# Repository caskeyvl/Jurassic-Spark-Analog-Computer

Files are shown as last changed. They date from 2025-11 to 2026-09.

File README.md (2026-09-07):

# Jurassic Spark Analog Computer
---

## NEW CAPSTONE GROUP - Intro
---

Hello new capstone group! We hope you're excited to continue to develop on top of this project. We hope you find a solid enough foundation built here to continue to expand from, and are excited to see where this project goes in the future.

Look around this repository, and familiarize yourself with it's layout and components. 

## Overview
---

Jurassic Spark's Analog Computer is a device that was designed to be used as the core of a course on control theory that will be offered in the future at CU Boulder. It is an educational device featuring 12 swappable module ports, with four different modules (adder, integrator, subtractor, and gain), each of which are a foundational building block that allow a student to quickly create and test a control design of their own making. Featured is also an on-board 4 channel oscilloscope, allowing students to visualize and compare waveforms produced.

To demonstrate some sort of control, in addition to the analog computer, a tertiary demonstrative device was developed. This device features a ping pong ball in a tube, with a fan that blows up and down the ball. Students will learn to develop and test different methods of controlling the height of the ball, through a feedback loop they develop on the analog computer itself. 

This repository contains all the design files and documentation for the Jurassic Spark Analog Computer, and the demonstrative tertiary system that goes along with it.

## Repository Structure
--- 

A quick description of what exists in each directory:

- **documentation** - design write-ups and reference docs for each subsystem, including [`BOM.md`](documentation/BOM.md) (master bill of materials) and [`Final_Report___Jurassic_Spark.pdf`](documentation/Final_Report___Jurassic_Spark.pdf) (our capstone final report — good background reading, but design details in the rest of this repo take precedence where they disagree)
- **hardware** - all PCB schematics and layouts (Altium `.SchDoc`/`.PcbDoc`), grouped per board: `modules/` (Adder, Gain, Integrator, Subtractor), `power/`, `oscilloscope-adc-hat/`, `mechatronic/`
- **mechanical** - enclosure/housing CAD (Parasolid `.x_t`, plus a `.3mf` for the printable module housing) for the module enclosures and full assemblies
- **mechatronic** - Arduino firmware for the mechatronic (ball-in-tube) system
- **oscilloscope** - all of the source code, along with a couple helper scripts, to the oscilloscope.
- **spice** - SPICE simulation files (`.wxsch`) for the individual analog computer modules (gain, integrator, adder/subtractor)

## Recommended Next Steps (to the new capstone team)
--- 

As you will find out, capstone moves quick, and you will never be able to get everything done that you want to get done. A few things worth picking up early:

- **Mechatronic/oscilloscope PCB bringup:** Unfortunately during our time, we were unable to make some quality of life revisions on the mechatronic PCB, and had to make a proto-board instead of a fully fledged PCB for the oscilloscope. Personally, I would begin here, ordering and verifying design, then reintegrating.
- **Case/power delivery issues:** We have noticed that particularly the gain module, for reasons we could not determine, do not get power delivered to them in certain module bays. It is particularly strange as it's only the gain modules that won't work in certain ports, when the adder/subtractor for example work as expected in those modules. May be worthwhile to consider the power delivery of our system and potentially rework it slightly, or at least figure out what the particular issue is with those certain ports. 
- **Better documentation:** One of the things we sort of ended up pushing off, that we highly reccomend learning from our mistake, is documentation. You will find yourself in capstone spending a lot of time on "documentation" that ends up being used for different capstone requirements, such as PDR, CDR, check ins, etc. We did not do a good enough job keeping this information accessible and separate from our capstone requirements, and thus, things that are more for the user (i.e. a simple user manual) didn't end up getting as much focus at it needed. As such, it might be helpful to spend some time as you try to understand our project and the design decisions that were made, to get some of this put together in a more streamlined manner for the sake of students who in the future will be using these devices.
- **Test bluetooth exporting for Windows:** A known issue that we weren't able to fix in time is exporting screenshots to Windows. In short, Windows requires pairing with the device before the OBEX OPP BlueTooth protocol can proceed and a file can be sent. To fix this, an agent is created that establishes a pairing for the duration of the transfer, and unpairs at the end, however this fix is not tested. The fix can be found in the `windows-bluetooth-pairing-proposal` branch, and once tested can be merged. 
- **`deploy.fish`:** this is a script that was written in order to cross compile the oscilloscope app for the Pi Zero 2W. As it stands, it's not functional as a custom Docker image is used that existed on Logan's local machine. Qt Creator (Qt's own IDE) has support for cross compilation built into the IDE, and is recommended to use their IDE and set up cross compilation through that. However, this is kept here for reference, and might be nice to convert to a bash script to be kept separate from Qt Creator (if you have issues with Qt Creator). 
- **Oscilloscope considerations:** The oscilloscope stack of tech used here works well enough for this application, though it might be worth it if you end up needing better performance to take a deeper dive into particularly hardware, and the PCB associated with the custom ADC solution.

## Contact
---

Feel free to reach out to [Logan Caskey](caskeyvl@gmail.com) with any questions or issues.

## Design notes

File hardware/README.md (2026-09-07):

# Hardware

Contains all of the PCB designs for this project. 

**Note:** `oscilloscope-adc-hat` contains the PCB files for our original and ultimately failed attempt to design our own custom adc hat for the Pi Zero2W using an ADS4195. Ultimately, issues with signal integrity were our downfall. We have included these files in case you decide to try to make this work again, but ultimately it was not included in our final design.

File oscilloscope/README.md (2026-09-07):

# Oscilloscope

A 4-channel oscilloscope built into the analog computer: a Raspberry Pi Zero 2W with a Waveshare ADS1263 ADC HAT, running a Qt/QML app that displays the four module signal channels, exports captures over Bluetooth, and drives the built-in LCD.

Hardware for this subsystem — the ADC HAT schematic/layout — lives in [`../hardware/oscilloscope-adc-hat/`](../hardware/oscilloscope-adc-hat/).

## How it works

**Acquisition (`datasource.cpp`)**: a dedicated thread (`adcThreadFunc`) talks to the ADS1263 over SPI, cycling through 4 single-ended channels (AIN0–AIN3 vs. AINCOM) on a DRDY interrupt. Wiring:

| Signal | Pin |
|---|---|
| DRDY | BCM 17 |
| CS | BCM 22 |
| RST | BCM 18 |
| SPI | `/dev/spidev0.0`, Mode 1, 4 MHz |

AINCOM is wired to the 2.5V rail (the system's virtual 12V mid-rail). A level-shifting board (see the hardware folder above) divides the module signals' 0–24V physical range down to 0–5V at the ADC input; with the ADS1263's ADC1 in bipolar mode and its internal 2.5V reference, that's a ±2.5V differential input mapped back out to the ±12V the UI displays.

Each sample gets an exponential moving average filter (`setFilterAlpha`, 1.0 = off) before landing in a mutex-protected ring buffer (`ScopeRing`, default 9000 samples ≈ 5s window). A level trigger (`Trigger`) gates rendering — nothing draws until the trigger channel crosses its level, and it stays armed-off until `rearm()` is called. The QML side's 25Hz timer calls `updateChannel()` on the main thread to copy the current view window into a chart series.

The window is specified in seconds (`setWindowSeconds`), not samples; `m_samplesPerView` is recalibrated automatically from the *measured* frame rate every 200 frames, so the displayed time window stays accurate regardless of the ADC's actual achieved throughput.

**No hardware fallback**: if `/dev/spidev0.0` isn't available (e.g. running the UI on a desktop for development), the ADC thread falls back to a synthetic signal generator so the UI still works without a Pi.

**Export**: `exportCsv()` writes the current view to CSV (per-channel columns gated by an enabled-channels list). `BluetoothExporter` (`bluetoothexporter.cpp`) handles device discovery and file transfer over BlueZ/D-Bus, using OBEX OPP — no pairing required, works with any discoverable nearby device.

**UI**: QML (`qml/qmloscilloscope/`), Qt Charts for the trace, running on Weston/Wayland on the Pi. `ScopeView.qml` is the scope display; `SettingsPanel`/`TriggerSettingsPanel`/`AxisSettingsPanel`/`ExportDataPanel` are the slide-out drawers.

## Building (desktop, for development)

```
cmake -B build -S .
cmake --build build
```

Requires Qt6 (Charts, Core, DBus, Gui, Qml, Quick) and a threads-capable toolchain. This builds and runs on a regular desktop Linux box using the synthetic-signal fallback (see above) to be used to test UI and such without having to deploy to the Pi.

## Cross-compiling and deploying to the Pi

The target is a Raspberry Pi Zero 2W running **Raspberry Pi OS Bookworm, 64-bit (aarch64)**. `toolchain.cmake` + `deploy.fish` implement this; getting the pieces below right the first time saves a lot of headache and work later, so full write-up instructions included here.

There are two one-time setup pieces, then a repeatable build+deploy step.

### 1. A sysroot pulled from a real Pi

`toolchain.cmake` expects a sysroot at `~/sysroots/rpi-bookworm-arm64` holding the target's `/usr` (Qt6 libraries, headers, and the target's own `Qt6Config.cmake` under `usr/lib/aarch64-linux-gnu/cmake/Qt6/`), plus `/opt` and a `lib -> usr/lib` symlink matching Raspberry Pi OS's merged-`/usr` layout:

```
mkdir -p ~/sysroots/rpi-bookworm-arm64
rsync -avz --rsync-path="sudo rsync" <pi-host>:/usr/ ~/sysroots/rpi-bookworm-arm64/usr/
rsync -avz --rsync-path="sudo rsync" <pi-host>:/opt/ ~/sysroots/rpi-bookworm-arm64/opt/
ln -s usr/lib ~/sysroots/rpi-bookworm-arm64/lib
```

Pulling it straight off a running Pi (rather than, say, `apt-get install` target packages or installing some other way) guarantees the libraries you link against are exactly what's on-device. This rsync will end up being large and slow, so give it time to complete. Re-run if, for any reason, the Pi's Qt6/system packages get upgraded. 

### 2. A cross-compile Docker image

The container needs the `aarch64-linux-gnu` cross-compiler *and* a **host-native** (x86_64) Qt6 install. `moc`/`rcc`/`qmlimportscanner` have to run on the machine doing the building even though the binary they help produce targets arm64, which is what `toolchain.cmake`'s `QT_HOST_PATH` / `Qt6HostInfo` settings are pointing at.

The one thing that actually matters here, learned the hard way: **don't** try to install target-architecture (arm64) Qt6 packages into the container, as that path is fragile and kept breaking. Target Qt6 comes entirely from the sysroot above; the container only ever needs Qt6 for its own (host) architecture:

```dockerfile
FROM debian:bookworm
ENV DEBIAN_FRONTEND=noninteractive

RUN apt-get update && apt-get install -y \
    cmake ninja-build pkg-config rsync openssh-client \
    gcc-aarch64-linux-gnu g++-aarch64-linux-gnu binutils-aarch64-linux-gnu \
    qt6-base-dev qt6-base-dev-tools qt6-declarative-dev-tools \
    qt6-tools-dev-tools qt6-charts-dev \
    libgl-dev libglx-dev libegl1 \
    && rm -rf /var/lib/apt/lists/*

WORKDIR /work
```

```
docker build -t qt-cross-bookworm:dev -f Dockerfile .
```

### 3. Build and deploy

With both of the above in place, edit `PI_HOST` near the top of `deploy.fish` to your Pi's SSH host (user@hostname), then:

```
./deploy.fish
```

It cross-compiles inside the Docker image against the sysroot (using `toolchain.cmake`), then rsyncs the resulting binary to the Pi. Note that it doesn't check the Docker build's exit status or consistently bail on a missing toolchain file, so a failed/skipped build can rsync a stale binary and still report success. Qt Creator's built-in cross-compilation support is a good alternative once its kit is pointed at the same sysroot + toolchain file. Check [this useful presentation](https://runebook.dev/en/docs/qt/cross-compiling-qt) for more info on how to set this up through QtCreator.

**Network note**: SSH to the Pi doesn't seem to work over CU/school wifi — deploying (or SSHing in at all) needs you on a network that actually allows it, like a personal hotspot or the capstone lab's own wifi. Worth confirming before you assume `deploy.fish` is broken when it's actually just the network.

### On the Pi itself

Raspberry Pi OS Bookworm (64-bit), running the app under a **Weston/Wayland** compositor session with SSH and mDNS (`.local` hostname resolution) enabled so `deploy.fish` can find it. A full SD card image capturing this exact setup is planned, to make this setup much easier — check with whoever's holding this repo for where to get it once it exists.

## Known issues

- **Voltage noise on the displayed trace**, worse at higher gain settings. Root cause: the level-shifting board shares analog/digital ground routing, and the SPI traces between the ADC and the Pi are relatively long. Neither the ADS1263's hardware FIR filter nor the software EMA filter fully hide it. A future PCB revision with a split analog/digital ground plane, shorter SPI traces, and more decoupling at the ADC's supply pins should reduce this substantially — this was root-caused but not yet re-fabricated.
- `deploy.fish` doesn't fail loudly on a bad cross-compile — see above.
- **Bluetooth export doesn't work to Windows receivers.** `BluetoothExporter` sends over OBEX OPP with no pairing step, matching Linux's behavior: an unpaired device just gets an "accept this file?" prompt. Windows' Bluetooth stack requires the two devices to already be paired before it'll accept an incoming OBEX transfer — there's no pairing flow in the app, so a Windows receiver has to be paired via Windows' own Bluetooth settings first, outside the app, or the send silently fails to prompt anything on their end.

  A fix is written and builds clean, but is **not merged** — it needs testing against real Windows hardware first, which wasn't available while writing it. See the `windows-bluetooth-pairing-proposal` branch: adds a `BluetoothPairingAgent` (BlueZ `Agent1`, `NoInputNoOutput` → "Just Works" pairing) and routes `sendFile()` through a pair-if-needed step before the existing OBEX flow. Before merging: build it, pair against an actual Windows machine, confirm the transfer completes, and confirm the existing Linux/Android/macOS path still works unchanged.

## Generating API docs

Header comments (`datasource.h`, `bluetoothexporter.h`) are Doxygen-formatted. With [Doxygen](https://www.doxygen.nl/) installed:

```
cd oscilloscope
doxygen
```

Output goes to `docs/html/index.html` (gitignored. Regenerate rather than committing it). QML isn't included, but rather documented here instead.

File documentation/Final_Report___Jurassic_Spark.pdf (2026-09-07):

# Jurassic Spark: Analog Computer

### ECEN 4620

Control theory and feedback loops are fundamental aspects of electrical engineering. However, students often struggle to understand these concepts due to abstract control equations and simulations that hide real-world effects. Our Analog Computer addresses this with swappable analog modules, a mechatronic ball-levitation demonstrative system, and an embedded oscilloscope — giving students a fully tactile, visual experience with closed-loop control.

Sponsored By: Professor Marco Nicotra

Logan Caskey - Dakota Golden - Joel Ramos Silva - Eric Chen - Zanghyeoun Shim

CONTENTS | CONTENTS

## Contents

1 Executive Summary | 2
2 Requirements | 8
3 The Technology Options | 10
4 The How | 13
5 Analysis | 18
6 So What? | 21
7 Journey Reflection | 27
ECEN 4620 | 1 | Spring 2026

1 EXECUTIVE SUMMARY

## 1 Executive Summary

### 1.1 Product Overview

High-Level Operation
First, based on pre-determined control logic, the student will insert some assortment of the four modules (i.e., integrator, gain, subtractor, and adder) into the computer housing.

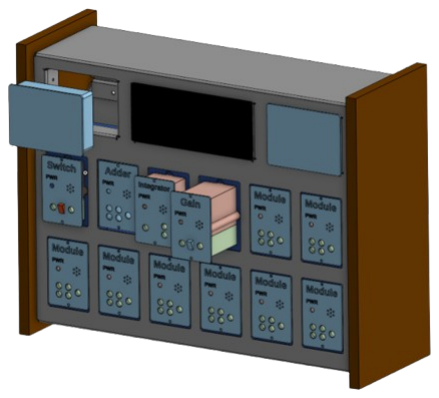
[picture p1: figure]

Figure 1: Modules being inserted into computer chassis.

From here, the student will begin developing the control signal. The next step is to route the output of the sensor from the mechatronic system to the computer, which will provide information about where the ball is positioned in the tube.

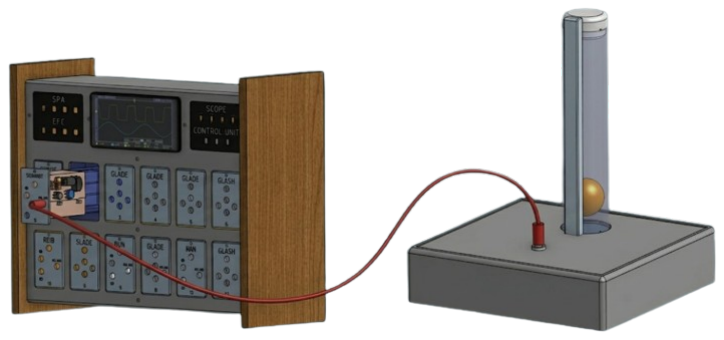
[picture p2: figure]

Figure 2: Information about the current ball height comes from the sensor in the mechatronic system.

ECEN 4620 | 2 | Spring 2026

1.1 Product Overview | 1 EXECUTIVE SUMMARY

To establish a reference voltage, the student must connect the 12V supply located at the top of the computer to a gain module set in the 0-1 mode. Continuing to connect the inputs and outputs between the modules, the student develops a control signal. This control signal feeds back into the mechatronic system, closing the loop.

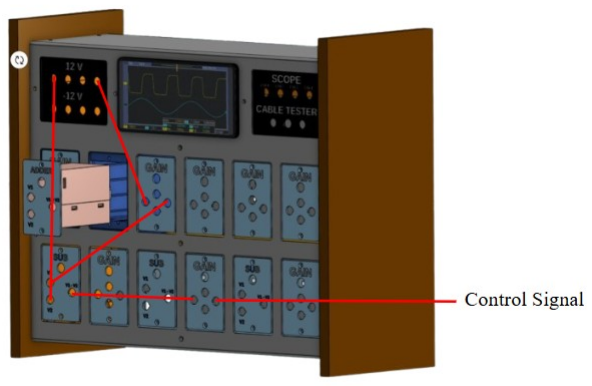
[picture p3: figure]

Figure 3: Routing the inputs and outputs of the modules develops a control signal.

Finally, with the control signal established and the feedback loop closed, the student observes the ball maintain a constant height as the fan in the mechatronic system dynamically adjusts its speed. Moreover, the student can compare the reference voltage with the voltage corresponding to the height of the ball, for example, by connecting these signals to the embedded oscilloscope on the computer.

ECEN 4620 | 3 | Spring 2026

1.2 Value | 1 EXECUTIVE SUMMARY

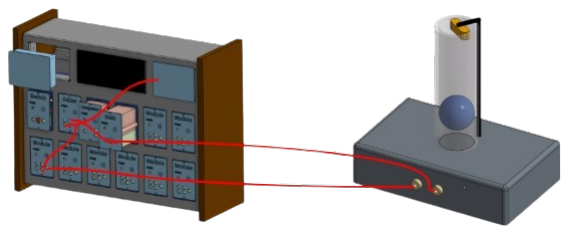
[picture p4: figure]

Figure 4: Full operation of analog computer.

### 1.2 Value

The underlying objective of this product is to create an interactive and intuitive platform for students to experiment with control laws. One of the key ways this is accomplished is by creating a design in which multiple different feedback operations can be implemented and tested quickly. For example, the figure below shows the feedback path we demonstrated at EXPO.

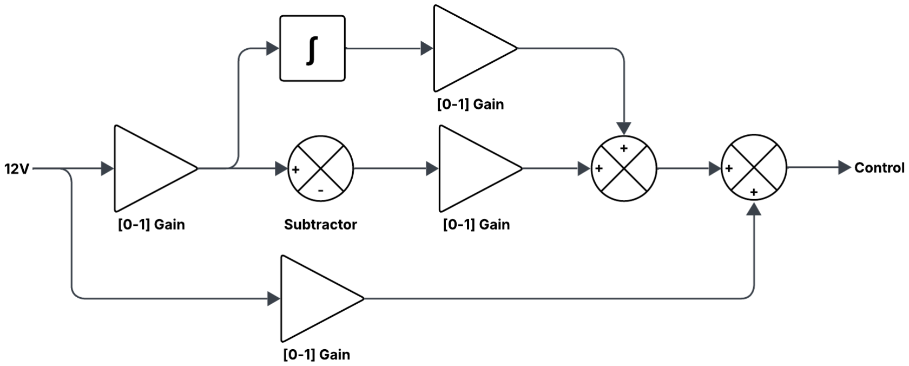
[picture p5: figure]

Figure 5: Feedback path demonstrated at EXPO.

ECEN 4620 | 4 | Spring 2026

1.3 Key Features | 1 EXECUTIVE SUMMARY

This feedback configuration represents only one example of the many control laws that can be implemented using the Analog Computer. By rearranging modules and modifying signal paths, students can create a wide range of feedback architectures to explore different system responses and controller behaviors. The modular design encourages experimentation by allowing users to quickly insert, remove, or reorder operations without rebuilding an entire circuit. Each gain module also includes a selectable range switch and potentiometer, enabling users to tune the gain continuously within either a 0–1 range or a 1–10 range. This flexibility allows for both fine adjustments and larger scaling changes, giving students greater control when tuning feedback performance.

Another key source of value comes from the system’s ability to bridge the gap between theoretical control concepts and physical behavior. By allowing students to directly observe how changes in feedback structure, gain, and signal flow affect a real system, the Analog Computer creates a more intuitive learning experience than simulations alone. Students can quickly compare different controller configurations, visualize signal responses in real time, and develop a stronger understanding of how control laws influence system stability and performance. The modular and durable design also supports repeated experimentation, making the platform well suited for long-term educational use in laboratory and classroom environments.

### 1.3 Key Features

Several key features were incorporated into the Analog Computer to improve usability, safety, and educational value. Each module includes an LED saturation indicator that alerts the user when the internal op-amp is approaching or reaching its output limits, helping students recognize nonlinear behavior and understand the practical limitations of analog control systems.

ECEN 4620 | 5 | Spring 2026

1.3 Key Features | 1 EXECUTIVE SUMMARY

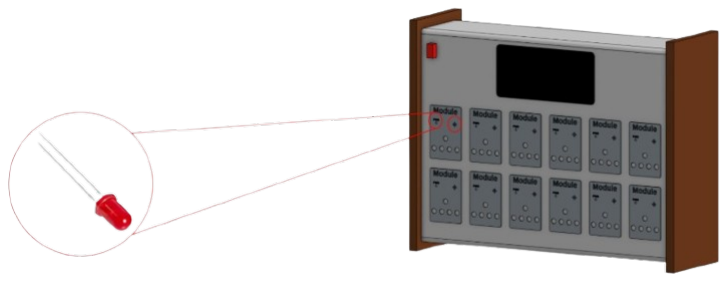
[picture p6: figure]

Figure 6: LED on each module conveys saturation.

Additionally, custom input and output connectors are also used throughout the platform to reduce the possibility of miswiring, ensuring that signals are routed correctly between modules and protecting the system from incorrect connections.

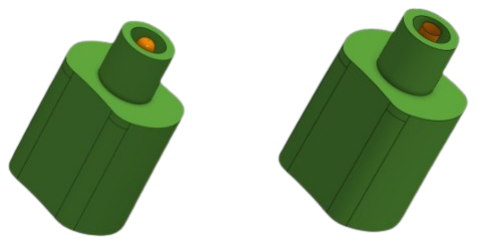
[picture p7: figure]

Figure 7

Finally, the modular architecture allows students to quickly insert, remove, and rearrange functional blocks without rewiring an entire circuit, enabling rapid experimentation with different feedback paths. Integrated signal monitoring further enhances the learning experience by allowing users to observe control signals and intermediate node voltages in real time, providing immediate visual feedback during system tuning and analysis.

ECEN 4620 | 6 | Spring 2026

1.4 Performance | 1 EXECUTIVE SUMMARY

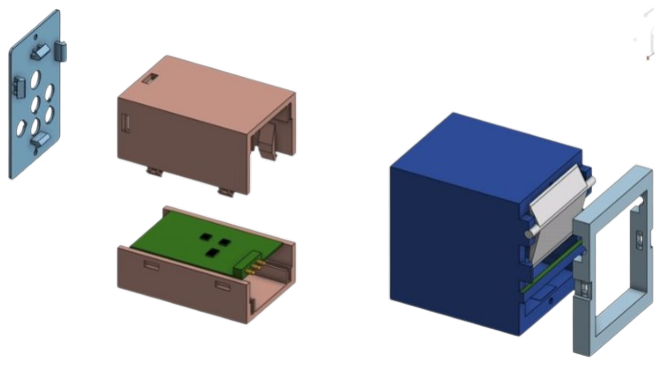
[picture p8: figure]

Figure 8: Housing for PCB modules.

### 1.4 Performance

Overall, the Analog Computer performed well and successfully met the primary requirements established for the intended user experience. The system allowed students to construct and modify feedback paths using interchangeable modules, observe system response in real time, and interact with a physical mechatronic demonstration. During testing and demonstration, the platform was capable of producing stable control behavior and provided a clear visualization of how different control laws influenced system performance. The modular design also functioned as intended, allowing modules to be inserted, removed, and rearranged quickly without requiring extensive setup time.
While the system achieved its fundamental objectives, there remains significant opportunity for refinement and improvement. One of the most noticeable limitations was voltage noise present within the integrated oscilloscope display, which occasionally reduced signal clarity and made small waveform details more difficult to interpret. Additional filtering, improved grounding strategies, and further PCB layout optimization could reduce this noise and improve measurement quality. Future iterations could also improve overall packaging, signal routing, and subsystem integration to create a more polished and robust educational platform.
ECEN 4620 | 7 | Spring 2026

2 REQUIREMENTS

## 2 Requirements

The requirements for the Analog Computer were developed to ensure the system provided an intuitive, safe, and educational platform for experimenting with control theory concepts. These requirements originated from both customer expectations and engineering constraints, focusing on modularity, ease of use, signal visualization, and physical demonstration of feedback control. The intended customer experience centered around allowing students to quickly assemble feedback paths, observe real-time system response, and interact with a tangible control system rather than relying solely on simulation software.

Several primary use cases guided the design of the product:

- Students select and insert modules corresponding to desired control operations such as gain, integration, addition, or subtraction.
- Students route sensor signals between modules to construct a feedback path and generate a control signal.
- Students adjust potentiometers on gain modules to tune controller response and observe system behavior.
- Students connect signals to the integrated display to visualize waveforms and intermediate control signals in real time.
- Students close the loop with the mechatronic system and observe the ping pong ball maintain a stable height within the tube.
- Professors can rearrange modules quickly to demonstrate multiple control laws during classroom instruction.

Several marketing and engineering requirements were successfully implemented in the final design:

- Modular add/subtract, gain, integrator, and switch functionality.
- Swappable modules capable of being inserted and removed quickly.
- Integrated oscilloscope display for real-time signal monitoring.
- Mechatronic feedback demonstration using a fan-driven ping pong ball system.
ECEN 4620 | 8 | Spring 2026

2 REQUIREMENTS

- Saturation indication using LEDs to alert users when op-amp limits are reached.
- Custom connector system designed to reduce miswiring between inputs and outputs.
- Compact, bench-top enclosure suitable for classroom and laboratory use.
- Fully manufacturable system using on-campus fabrication resources.

While many core requirements were achieved, several features remained stretch goals or areas for future refinement:

- Improved oscilloscope signal quality with reduced electrical noise.
- Additional module types such as comparator, inverter, or low-pass filter modules.
- Expanded tertiary systems beyond the ping pong ball demonstration.
- More advanced data logging and waveform storage functionality.
- Increased robustness of signal routing and cable management.
ECEN 4620 | 9 | Spring 2026

3 THE TECHNOLOGY OPTIONS

## 3 The Technology Options

### 3.1 Analog Computer

The analog computer, being the main component of our project, deserved some of the most consideration for technology options. Due to our requirements aforementioned, we knew we wanted a robust and high-performing RRIO op-amp, and slew rate wasn’t that big of a concern, since these control loops are going to be "slow" dc-circuits. With these requirements, we considered using an op-amp that every electrical engineering student at CU Boulder is familiar with - the TLV272 from Texas Instruments. Ultimately, this didn’t meet our desire to have a "12 volt bipolar" system, as the TLV272 can only operate on up to 16 volts. However, this provided a blueprint to find the op-amp we ultimately went with - Texas Instrument’s OPA196 family. With it being operable to up to 32 volts, as well as some quality of life features baked in such as overvoltage and short circuit/overcurrent protections, it made this the clear choice to help meet our requirement of a robust and "student-proof" system as well, and has proven to be a very effective and accurate op-amp for our system.
To meet the requirements of detecting saturation, we chose to go with a dual package LM393 comparator to build a window-comparator circuit to detect when our op-amp outputs are swinging close to the max output (with a .5 volt window from either power rail). The LM393 was a clear choice for this application, as really just about any comparator that accepts our voltage range of 0-24 volts would work, and the LM393 in particular is a tried-and-true component, being extremely cheap and extremely common.

### 3.2 Oscilloscope

The embedded oscilloscope was the "subsection" of our technology requirements in which we had possibly the most freedom, as there were not a lot of strict requirements or requirements at all for how to implement this feature. Ultimately, we knew that it didn’t have to be the most precise or high-speed oscilloscope, and could be a rather "bad" oscilloscope by modern standards, as it will be used primarily to look at DC signals and nothing higher than 100 Hz, if at all. Thus, there was a lot of avenues we could have taken to meet those basic requirements, even going as far as to implement a complete system such as the Analog Discovery 2 from Digilent, which would have the benefit of being way more accurate and better made than anything we’d actually need in this project, as well as a

ECEN 4620 | 10 | Spring 2026

3.3 Mechatronic System | 3 THE TECHNOLOGY OPTIONS

strong likelihood that the students taking this course would already be in part familiar with this system as they use this device in the electronics design laboratory course, a prerequisite for electrical engineering students.
However, because our sort of atypical system being a pseudo-bipolar system, we ultimately decided on doing a custom solution. For a custom solution that requires a front-end, a Raspberry Pi is the clear choice, due to its ability to give us access to all the power and flexibility with Linux. Out of the Raspberry Pi family of micro controllers, we decided on using a Zero 2 W, primarily for physical form-factor concerns, while still having the ability to use wireless features including WiFi and Bluetooth. Ultimately, we ended up using Qt as our application development framework, as it’s very robust and has great documentation, as well as literally had an oscilloscope example baked in to its IDE, and greatly simplified the front-end development cycle. C++ was incorporated for data processing and communication to our ADC.
As far as the ADC we chose, we ended up going with a Waveshare Raspberry Pi hat breakout module built around the ADS1263, a 10-channel 32 kSPS ADC. This means that with 4 channels integrated, we were getting around 8 kSPS per channel, which was more than fine for the scope of this project. This required a secondary custom PCB to level shift inputs down to the acceptable 5 volt range, however, which was not ideal compared to our original custom PCB hat solution that would do that along with powering the Pi itself.

### 3.3 Mechatronic System

The primary concern for the mechatronic system ended up being the sensor, and how we sense the ball overall. Multiple sensors and methodologies were attempted, including ultrasonic sensors, an analog time-of-flight sensor, and multiple digital time-of-flight sensors. The primary issue was the ultrasonic sensor had slight issues with the wind from the fan affecting readings (not to mention not being too accurate in the first place), and a combination of issues with light-based sensing methods, primarily due to the light being internally reflected in the acrylic tube, which was a strict requirement in this project, so students could actually see the ball inside our tube. Due to the reflections we were experiencing, we looked into sensors that had the ability to adjust its region of interest for measurements, which led us to a breakout module from Adafruit that incorporates ST’s VL53L1x time of flight sensor. It has a 4 m range, and allows you to adjust the region of interest down to a 5 degree "cone", which proved to be absolutely vital for the success of this system and was implemented with great success.

ECEN 4620 | 11 | Spring 2026

3.3 Mechatronic System | 3 THE TECHNOLOGY OPTIONS

The fan was a driving factor for a lot of our choices overall for mechatronic system, as we wanted to pick something that would be relatively easy to implement, rather than having to deal with motor control issues ourselves, while still meeting our requirements of "analog control", and being powerful enough to actually lift the ball with high static-pressure ratings. Because of these considerations, we decided to go with a PC case fan, as it would be easily controllable with a PWM signal and greatly simplify aspects of our integration. The specific fan we chose is the NF-F12 industrialPPC-3000 PWM from Noctua, as it was designed as a server-rack fan and thus has high static pressure ratings (to get good airflow in constricted environments), while still having all the features and ease of use of a traditional PC fan.
To interface these components and act as a sort of "translation layer" between everything, we needed a microcontroller. We ultimately decided to go with an Arduino Nano, as they are extremely simple to work with, and had libraries readily available for the sensor we were using. It would effectively read the signal passed from the computer, map that directly to a PWM duty-cycle for the fan, and spit the sensor reading values out as analog voltages to be sent back to the Analog Computer.
ECEN 4620 | 12 | Spring 2026

4 THE HOW

## 4 The How

### 4.1 Functional Block Diagram

The Analog Computer can be understood as a closed-loop system that connects four major subsystems: the Bank of Modules, the Integrated Oscilloscope System, the Power Distribution Unit (PDU), and the Mechatronic Set-Up.

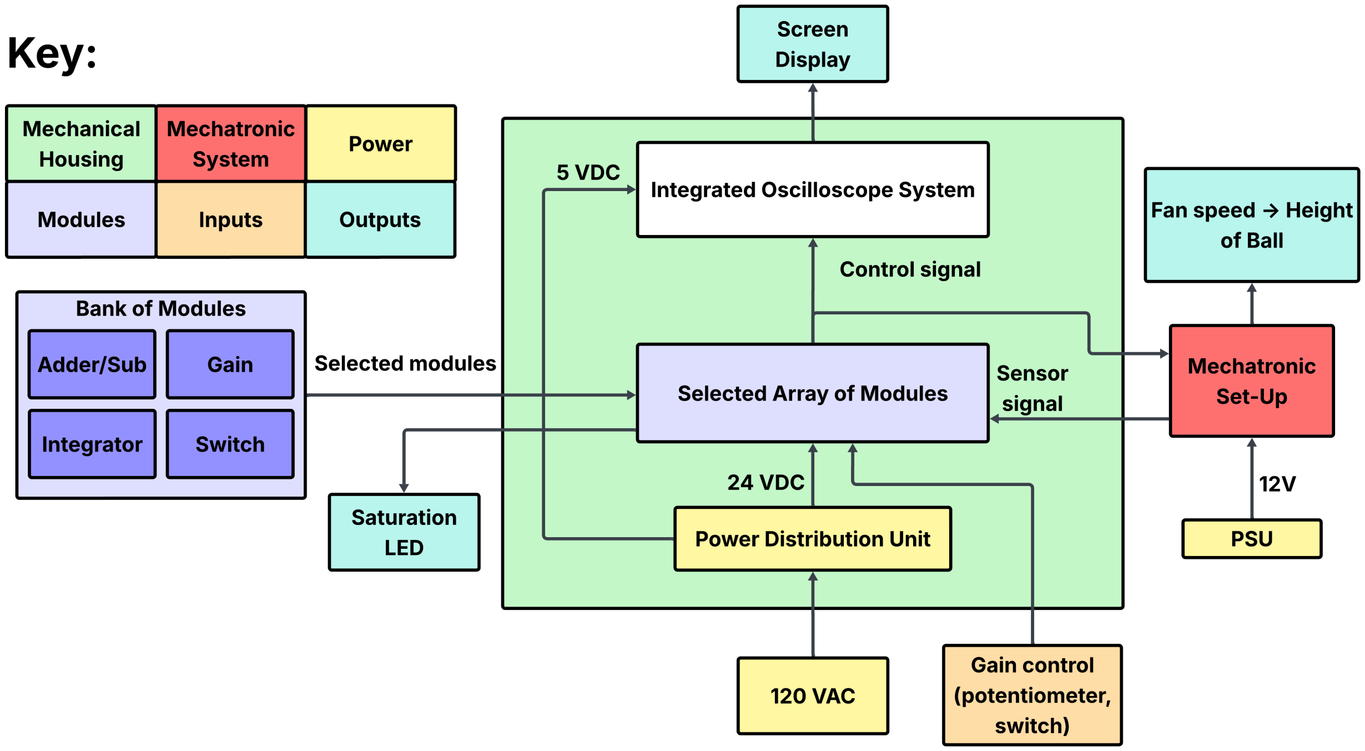
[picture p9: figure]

Figure 9: Functional block diagram for the Analog Computer.

### 4.2 Bank of Modules

### 4.2.1 Module Mechanical Design

Each module consists of a 3D-printed enclosure that houses a custom PCB. Power is delivered to each module passively via pogo pins on the rear face that mate with a spring-contact rail on the back-plane when the module is inserted, eliminating the need for a separate power connector. Banana jacks on the front face expose the signal input and output ports. A front-mounted indicator LED and buzzer driven by an LM393-based saturation detection circuit alert the student when the op-amp output approaches the supply rails.

ECEN 4620 | 13 | Spring 2026

4.2 Bank of Modules | 4 THE HOW

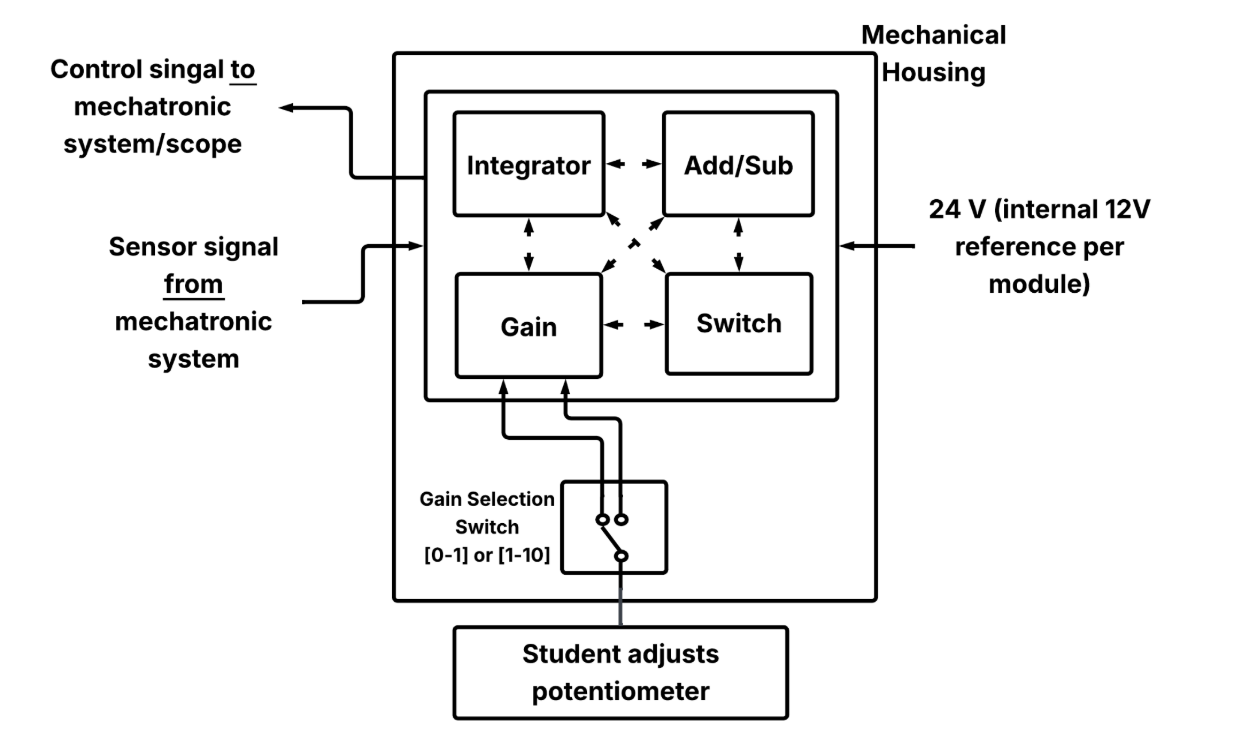
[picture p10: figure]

Figure 10: Functional Block Diagram of the Modules

### 4.2.2 Adder / Subtractor Module

The adder/subtractor is a single PCB implementing a classic differential-amplifier topology using OPA196 op-amps. Two banana-jack inputs feed the non-inverting (add) path and two feed the inverting (subtract) path through matched 100 kΩ resistors, giving the output:

Vadd = 12 − (Vin1 + Vin2)

A 12 V virtual-ground reference generated on-module from the 24 V supply defines the signal midpoint, so the usable output swing spans −12 V to +12 V. The module does not include saturation detection, because the differential topology self-limits at the supply rails without runaway behaviour.

### 4.2.3 Gain Module

The gain module provides selectable gain ranges of [0, 1] and [0, 10] via a front-panel toggle switch. Each range is implemented with a separate inverting amplifier stage using OPA2196 op-amps, and an additional inverter stage corrects the sign inversion introduced by the amplifier so the output polarity matches the input. A

ECEN 4620 | 14 | Spring 2026

4.3 Power Distribution Unit | 4 THE HOW

100 kΩ potentiometer accessible on the front panel sets the feedback resistance, allowing the student to tune the gain continuously within the selected range. An LM393 window comparator monitors the output and illuminates the saturation LED/buzzer when ∣Vout∣ approaches 12 V.

### 4.2.4 Integrator Module

The integrator module uses an OPA2196 in the classic integrator configuration. The 12 V virtual-ground reference keeps the quiescent output centered at midrail. The same LM393-based saturation sensing used in the gain module is included here because the integrator is the module most susceptible to slow drift to saturation under student use. Integration is susceptible to continued integration on small DC offsets, requiring the saturation detection to be present so students will know when that drift has occurred over time.

### 4.2.5 Switch Module

The switch module routes one of two selectable input signals to a single output. Students use it to inject a reference setpoint into the control loop or to toggle between two signal paths mid-experiment. A front-panel toggle switch physically selects between the two banana-jack inputs; no active circuitry is required, keeping the module simple and reliable.

### 4.3 Power Distribution Unit

The PDU accepts 120 VAC from a standard three-prong wall outlet. A Mean Well LRS-150-24 enclosed switching power supply converts the mains input to a regulated 24 VDC bus at up to 6.25 A (150 W). The 24 V bus is distributed to each module slot via a custom PCB that provides one pogo-pin rail contact per slot; adding or removing modules changes the load but does not interrupt power to the remaining slots. A Traco Power TSR 2-2450N non-isolated buck converter steps the 24 V rail down to a stable 5 V output to power the Raspberry Pi Zero 2W and the LCD screen.

ECEN 4620 | 15 | Spring 2026

4.4 Integrated Oscilloscope System | 4 THE HOW

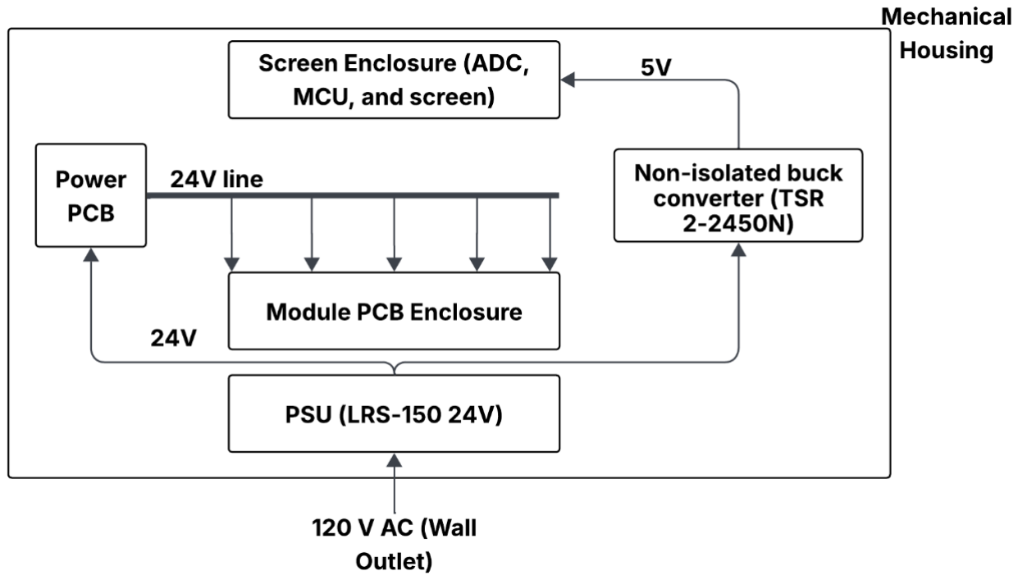
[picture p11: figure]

Figure 11: Functional Block Diagram of the Power System

### 4.4 Integrated Oscilloscope System

This system replaces an external bench oscilloscope with a self-contained, embedded display that students could use to observe control signals in real time without additional equipment.

ECEN 4620 | 16 | Spring 2026

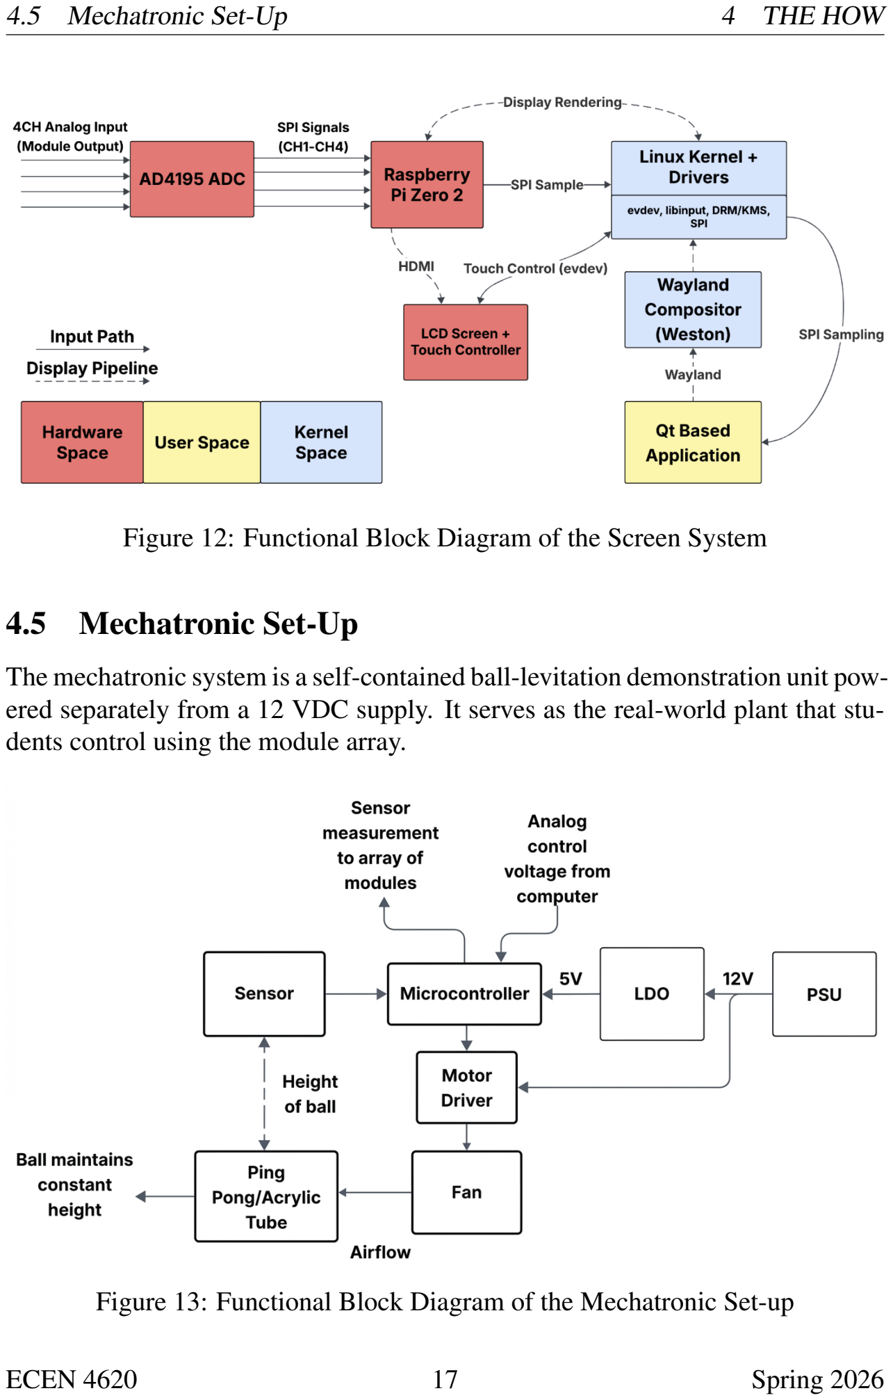
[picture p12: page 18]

4.5 Mechatronic Set-Up | 4 THE HOW

Figure 12: Functional Block Diagram of the Screen System

### 4.5 Mechatronic Set-Up

The mechatronic system is a self-contained ball-levitation demonstration unit powered separately from a 12 VDC supply. It serves as the real-world plant that students control using the module array.

Figure 13: Functional Block Diagram of the Mechatronic Set-up

ECEN 4620 | 17 | Spring 2026

5 ANALYSIS

## 5 Analysis

### 5.1 System-Level Performance

The Analog Computer successfully met its primary objective of providing a functional, hands-on platform for closed-loop control experimentation. During EXPO demonstration, the system achieved stable ball levitation within the mechatronic tube, with the fan responding dynamically to the control signal generated by the module array. People were able to construct a feedback path, observe the system response in real time on the embedded oscilloscope, and adjust gain to modify closed-loop behavior thus validating the core use case the system was designed for.
Of the marketing and engineering requirements established at the outset of the project, the majority were successfully implemented in the final design. Modular add/subtract, gain, integrator, and switch functionality was fully implemented. Modules can be inserted and removed from the backplane in seconds, and the pogo-pin power delivery system eliminated the need for any separate power connections when swapping modules. The custom connector system reduced miswiring by ensuring inputs and outputs could not be accidentally swapped. The platform was compact enough to be operated on a standard laboratory bench and was fabricated entirely using on-campus resources.

### 5.2 Oscilloscope and ADC Performance

The embedded oscilloscope system was built around the ADS1263 32-bit ADC, accessed via a Waveshare Raspberry Pi HAT breakout module. The ADC was configured to operate at 7,200 SPS total throughput, cycling across four input channels. With four active channels, the effective per-channel sample rate was approximately 1,800 SPS. For the intended application — monitoring DC signals and low-frequency control waveforms well below 100 Hz — this sample rate exceeds the Nyquist requirement by more than an order of magnitude, and was considered more than sufficient for our use case, with room to improve in the future.
The ADC was configured with a FIR digital filter for hardware-level noise rejection, and the Qt-based application provided a software exponential moving average (EMA) filter, adjustable from 0 to 1.0 in 0.01 steps, allowing students to trade temporal resolution for signal clarity. The ring buffer holds up to 100,000 samples, corresponding to approximately 55 seconds of continuous capture, and
ECEN 4620 | 18 | Spring 2026

5.3 Saturation Detection Analysis | 5 ANALYSIS

the default display window spans 5 seconds, configurable from 0.1 to 10 seconds. The display refreshes at 25 Hz, which was found to be sufficient for visualizing the slow control signals present in this system.
The primary limitation of the oscilloscope system was residual voltage noise on the displayed waveforms. The ADS1263 accepts a differential input range of ±2.5 V around its internal 2.5 V reference, with the system’s ±12 V range mapped down through a resistive level-shifting PCB. The additional signal conditioning stage introduced noise that was not fully suppressed by the hardware FIR filter or software EMA, particularly at higher gain settings. The root cause was identified as a combination of shared analog and digital ground routing on the level-shifting PCB and SPI signal integrity issues arising from the relatively long trace paths between the ADC and the Raspberry Pi. A split analog/digital ground plane, shorter SPI traces, and additional decoupling capacitors at the ADC supply pins would likely reduce this noise floor substantially in a future revision.

### 5.3 Saturation Detection Analysis

Each module (except the switch) incorporates an LM393-based window comparator circuit for saturation detection. The circuit was designed to trigger when the op-amp output approaches within 0.5 V of either supply rail, corresponding to reference voltages of Vref+ = 11.75 V and Vref− = 0.25 V relative to the virtual ground reference.
Testing of the saturation detection circuit confirmed that the comparator output remained above approximately 10 V during normal (non-saturated) operation, and fell below 150 mV when saturation was detected, providing a clean digitallike transition suitable for driving the indicator LED and buzzer. The LED turnon threshold was measured at approximately 7.8 V, and LED forward current at 12 V was measured at 3.4 mA, within the rated limits of both the LED and the LM393 open-collector output. Reference voltage accuracy was confirmed to within ±25 mV of the target values, and 330 kΩ hysteresis resistors were used to prevent rapid oscillation of the indicator near the saturation boundary. The saturation detection system performed reliably throughout testing and demonstration, and was one of the more polished subsystems in the final product.

### 5.4 Mechatronic System Analysis

The mechatronic system was validated through physical demonstration of sustained ball levitation. The VL53L1X time-of-flight sensor was configured with a

ECEN 4620 | 19 | Spring 2026

5.5 Summary | 5 ANALYSIS

4-SPAD region of interest (the minimum available) to produce a narrow sensing cone that negated reflections from the interior walls of the acrylic tube. A 50 ms measurement timing budget was used, yielding a sensor update rate of 20 Hz over I

2
C at 400 kHz. This update rate was consistent with the control loop bandwidth of the system, as the fan dynamics and ball inertia limited meaningful response to frequencies well below 20 Hz.
The Arduino Nano generated a 25 kHz PWM signal to drive the Noctua NF-F12 fan, a frequency chosen to place the switching noise above the audible range and to match the fan’s native PWM specification. Fan duty cycle was mapped linearly from the analog control input, with the PWM compare register ranging from 127 to 255 out of a period of 639 counts (corresponding to roughly 20% to 40% duty cycle), tuned empirically to span the useful levitation range within the tube without the ball bottoming out or escaping the top. The sensor output was converted back to an analog voltage via PWM-filtered DAC on a second output pin and returned to the Analog Computer as the feedback signal, closing the loop. A known limitation of the mechatronic system is that the Arduino’s PWMbased DAC output for the sensor feedback signal introduces quantization and ripple that appears as noise on the feedback path. A true DAC, or an RC filter with a lower cutoff frequency on the PWM output, would improve signal quality. Additionally, the control loop latency introduced by the 50 ms sensor measurement budget, Arduino processing time, and fan spin-up dynamics limited achievable loop bandwidth, which constrained how aggressively the gain could be set before the system became unstable.

### 5.5 Summary

Overall, the Analog Computer met the requirements that most directly affected the student experience: modular control operations, real-time signal visualization, and a physical demonstration of closed-loop feedback. The subsystems that fell short of their full potential — primarily the oscilloscope noise floor and the DAC resolution on the mechatronic feedback path — were both attributable to PCBlevel design decisions and component selection tradeoffs made under time and resource constraints. Both are well-understood problems with known solutions that would be straightforward to address in a future revision.

ECEN 4620 | 20 | Spring 2026

6 SO WHAT?

## 6 So What?

### Logan Caskey

- Leadership is hard. Really hard. As the team lead for this project, I really struggled to keep both myself and everyone on track and lead in general. I think I sort of treated the leadership role as somewhat synonymous with a technical lead role at times, which me also having the role of system architect didn’t really help that distinction in my mind, and I didn’t do enough of the actual leadership side of things at times. It taught me better ways to communicate with my team, and taught me some personal discipline that I don’t normally have surrounding these types of projects (in terms of trying to be on top of everything).
- SPI can be a nightmare On a more technical note, the biggest technical challenge for me this year by far was working on the oscilloscope. As system architect, I selected just about every single electrical component in our system, on both the computer side and mechatronic side, and I sort of naively chose components at times where I didn’t consider how hard it would be to implement, thinking that it would be fine. In particular, the ADC I selected was way overspecced for our use case, and I wanted the oscilloscope to be overspecced in general, but I sort of assumed it would be ok and that the integrity of our signal would be fine so long as we do some best practice PCB design things, and that ended up not being the case. Also, in selecting a QFN package component, we were unable to prototype soon, having to order a custom adapter online to be able to prototype on a breadboard, adding a lot of time delay in our project that wasn’t ever necessary, instead of choosing a more robust and proven part. As a result, I learned a LOT about SPI communication, its pitfalls, good circuit design practice in high speed digital circuits, the QFN package and how to work with it, and more.
- There will always be something "not perfect", and things will almost never go the way you plan As aforementioned with the ADC, there were definitely issues that took place during the duration of our project. I have a bad tendency to be a bit of a perfectionist on certain things, and was getting very frustrated at points through this year when things weren’t going the way I wanted or had envisioned them to. In some ways, I think that my perfectionism helped our group to turn out better work at points, but other
ECEN 4620 | 21 | Spring 2026

6 SO WHAT?

times I think it just turned into me having this sort of bad attitude that things weren’t turning out the way I wanted, and affected both me and my group negatively. I learned to sort of accept all the flaws that are going to come with our project, and that almost regardless of everything, there was no way I or my group could have lived up to my standards, and that’s OK.

### Dakota Golden

- Large projects are much more dependent on teamwork than I originally expected. Although I had completed group projects before Capstone, this was the first time I worked with the same team on a technically complex project over the course of an entire academic year. One of the biggest takeaways for me was realizing how much can be accomplished when multiple people contribute different skills toward a shared goal. Our final product only came together because responsibilities were distributed across the team, and everyone contributed to solving different technical challenges. Seeing the system progress from an idea into a functioning product reinforced how important communication, collaboration, and shared ownership are in larger engineering projects.
- PCB assembly and debugging are often harder than the design itself. A major technical challenge for me involved assembling and troubleshooting PCBs. Designing a board and receiving fabricated hardware felt like a significant milestone, but getting the board to work reliably introduced a completely different set of challenges. Surface-mount soldering required far more consistency and precision than I expected, and when a board failed, it was not always obvious whether the issue came from assembly mistakes, solder quality, or the circuit design itself. This process taught me patience and showed me how important manufacturing quality and structured debugging practices are when working with custom hardware.
- Subsystem integration is where a project begins to feel real. One area that stood out to me throughout the project was subsystem integration. Once individual boards and components were verified independently, combining them into a complete system required a different style of problem solving. I became more comfortable tracing signals, diagnosing interactions between subsystems, and validating that separate pieces of hardware worked together as intended. Integration work strengthened my debugging skills because
ECEN 4620 | 22 | Spring 2026

6 SO WHAT?

problems were often caused by the relationship between components rather than a single isolated failure.

- Planning early saves more time than rushing into implementation. Early in the project, a significant amount of time was spent developing block diagrams, power budgets, and risk analysis documents. At the time, much of this planning felt slower and less rewarding than immediately building hardware. However, throughout integration and troubleshooting, those early design documents became extremely valuable references. This project taught me that strong planning provides structure for decision making later in development, especially when systems become more complex and multiple subsystems must interact reliably.
- Testing early is worth the uncertainty. Looking back, I would have started ordering components and experimenting with hardware much earlier in the design process. Early on, I hesitated to commit to parts without confidence that they would work correctly, but I learned that uncertainty is unavoidable in engineering design. Earlier testing would have allowed us to identify risks sooner and iterate more effectively. This experience reinforced that prototyping and experimentation are not separate from design; they are essential parts of it.

### Joel Ramos Silva

- Mechanical design has to work closely with the electrical system. One of the biggest things I learned from this project was that mechanical design cannot happen separately from the rest of the system. Throughout development, enclosure size, mounting locations, connector placement, and internal spacing all changed as the electrical design evolved. Small mechanical decisions often affected how easy the system was to assemble and use, which showed me how important communication is between different parts of the project.
- Physical assembly reveals problems that CAD does not always show. Designing parts in CAD made it easy to visualize how everything should fit together, but many challenges only became clear once real hardware was assembled. Tolerances, alignment issues, wire routing, and spacing problems often appeared during integration even when the design looked correct on screen. This taught me that prototyping and test fitting are essential parts
ECEN 4620 | 23 | Spring 2026

6 SO WHAT?

of mechanical design, especially when multiple subsystems must fit into a limited space.

- Manufacturing and assembly matter just as much as functionality. A major takeaway from this project was learning to design parts that are not only functional, but also practical to build and assemble. Some components worked well in theory but became difficult to print, mount, or repeatedly install during testing. Over time, I learned to think more about assembly order, hardware access, material limitations, and long-term durability when creating mechanical parts.
- Iteration is a normal part of the design process. Very few mechanical components worked perfectly on the first attempt. Multiple revisions were needed to improve fit, strength, and overall usability. While redesigning parts could sometimes feel repetitive, this project taught me that iteration is a normal part of engineering and often leads to a much stronger final result.

### Eric Chen

- Strong teamwork is what allows a large project to succeed. One of the biggest takeaways from this project was learning how much can be accomplished when a team works well together over a long period of time. Developing the Analog Computer required consistent collaboration between multiple subsystems, and progress depended on everyone contributing to a shared goal. Working alongside the same group over the course of the year showed me that a coordinated team can solve problems and build a much stronger final product than any individual could accomplish alone.
- Planning early creates flexibility later in the project. Throughout the design process, I learned that planning before implementation is extremely important. Early decisions surrounding timelines, component selection, and subsystem dependencies had a large impact later during integration. Having clear plans and backup options helped reduce uncertainty when challenges appeared. This project reinforced that time spent organizing and preparing is not lost time; it creates opportunities to troubleshoot and adapt when things do not work as expected.
- PCB assembly takes more time and practice than expected. One of the more difficult technical areas for me involved PCB design and soldering.
ECEN 4620 | 24 | Spring 2026

6 SO WHAT?

While designing and ordering boards felt straightforward, assembling and debugging them required significantly more time than anticipated. Small soldering issues or component placement errors could create problems that were difficult to diagnose. This taught me that manufacturing and assembly skills are just as important as circuit design, especially when deadlines are involved.

- Asking for help is part of good engineering practice. A personal lesson I gained from this project was becoming more comfortable asking questions when I was unsure about something. Early on, I often tried to solve problems independently for too long, which sometimes slowed progress. Over time, I realized that reaching out to teammates or seeking advice usually led to faster solutions and stronger collaboration. Learning to ask for help improved both my efficiency and my confidence when working within a technical team.

### Zanghyeoun Shim

- PCB design requires mechanical awareness, not just electrical correctness. As the PCB Design Manager, I quickly learned that a schematic being electrically correct is only the starting point. Physical constraints — pad dimensions, board outline, component placement relative to the enclosure, and pogo-pin contact geometry — all had to be considered simultaneously. Designing a PCB that fits and functions inside a real mechanical housing was a genuinely different challenge from anything covered in coursework, and it made the work much more interesting.
- Hands-on testing and debugging are how system reliability is actually built. Iterating through test-fail-debug cycles on the fabricated boards taught me that reliability is not something you design in once and forget — it is something you verify repeatedly. Each debugging session deepened my understanding of where real hardware diverges from simulation, and gave me practical intuition that I could not have gained any other way.
- Noise reduction is a first-class design concern in mixed-signal PCBs. The most technically demanding part of my work was the ADC PCB for the integrated oscilloscope. Achieving clean waveforms on the LCD screen required minimizing noise at the ADC input, which meant the board layout itself had to do real engineering work. I created the ADC schematic symbol
ECEN 4620 | 25 | Spring 2026

6 SO WHAT?

and PCB footprint library from scratch, studied multiple datasheets, and sought expert advice before settling on a split analog/digital ground plane strategy. Seeing the improvement in signal quality after implementing the ground separation was one of the most satisfying moments of the project.

- Owning the full PCB lifecycle is an invaluable experience. Taking a design from initial schematic capture all the way through layout, fabrication order, assembly, bring-up testing, debugging, and final integration into the complete system gave me a complete picture of what professional PCB development looks like end-to-end. There is still a great deal more to learn as a PCB designer, but having navigated the entire process once — with real stakes — is a foundation I will build on throughout my career.
ECEN 4620 | 26 | Spring 2026

7 JOURNEY REFLECTION

## 7 Journey Reflection

Throughout the development of the Analog Computer, our team learned that large engineering projects depend just as much on communication and coordination as they do on technical ability. Because the system combined analog electronics, PCB design, embedded software, mechanical integration, and a mechatronic demonstration, progress relied heavily on collaboration between team members. One process that worked particularly well was dividing ownership of subsystems while maintaining regular communication. Each team member had a primary area of responsibility, allowing work to progress in parallel while remaining connected to the larger system. Weekly meetings and troubleshooting sessions helped keep development aligned with project goals.
Brainstorming was most effective early in the design process when the project scope was still flexible. Ideas were evaluated on technical feasibility, educational value, manufacturability, and usability. Rather than committing immediately to a single approach, the team benefited from comparing multiple options before implementation.
Decision making followed a balance between technical ownership and group consensus. Subsystem owners often led detailed design decisions, while larger architectural choices were discussed collectively. This allowed expertise to guide implementation without slowing progress through excessive debate.
One of the largest lessons learned involved the importance of testing and iteration. Many assumptions about integration, signal quality, and manufacturability changed once physical hardware existed. The project reinforced that debugging is not a separate stage after design, but a continuous process that shapes the final system.
If completing a similar project again, the team would begin prototyping and subsystem validation earlier. Earlier testing would have reduced uncertainty and created more time for refinement rather than late-stage troubleshooting. Stronger documentation between subsystems would also simplify integration and debugging.
Overall, the project demonstrated that successful engineering comes from planning, communication, experimentation, and persistence. While the Analog Computer met its primary goals, the larger takeaway was learning how to organize, adapt, and solve problems together while developing a complex system from concept to implementation.
ECEN 4620 | 27 | Spring 2026

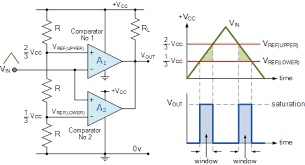
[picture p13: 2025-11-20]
documentation/Saturation_Sensing/Images/Window.png

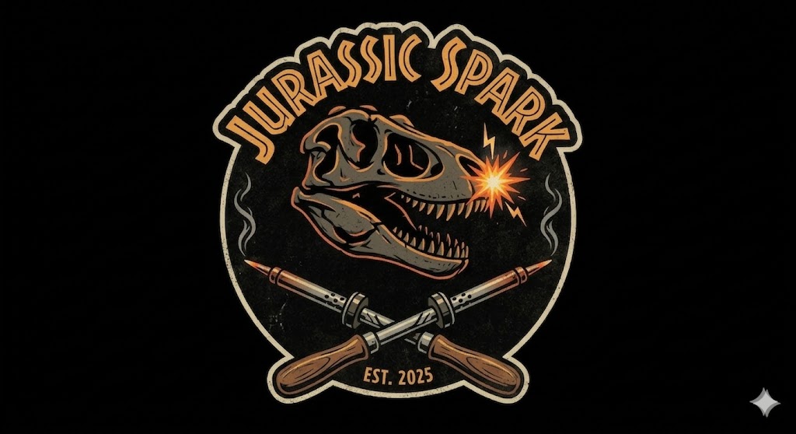
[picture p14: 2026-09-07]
imgs/jurassic_spark.jpg

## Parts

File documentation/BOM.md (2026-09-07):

# Bill of Materials

This is pulled from the project's PDR (Preliminary Design Review) parts-costing tab, since a fully updated final BOM was never delivered by the finance manager side of the project.

Treat this as a real, working parts list — not a final invoice. Some items below were superseded as the design matured past PDR (called out under "Known changes since PDR"), and all prices are PDR-stage quotes/estimates rather than confirmed final purchase prices. Cross-reference against `hardware/` and `mechanical/` before ordering anything.

## Known changes since PDR

- **Oscilloscope ADC/mux**: the PDR plan used a 16-channel multiplexer (`CD74HC4067`) to route module signals into an ADC. The final design instead uses a single Waveshare ADS1263 ADC HAT (10-channel, native differential inputs) that reads all 4 module channels directly — no external mux needed. See [`../hardware/oscilloscope-adc-hat/`](../hardware/oscilloscope-adc-hat/) and `../oscilloscope/README.md`. The HAT's own part number/price isn't in the PDR sheet and needs to be added (Waveshare "ADS1263 ADC HAT").
- **Mechatronic sensing**: the PDR plan used 3x Microchip `MCP3204` 4-channel ADCs, presumably for analog ball-position sensing. The final mechatronic system instead uses a VL53L0x time-of-flight distance sensor (per the Arduino firmware in `../mechatronic/`) — the MCP3204 line below was not used in the final build. VL53L0x part/price needs to be added.
- **Custom oscilloscope ADC HAT (ADS4195)**: an earlier, ultimately abandoned attempt at a custom ADC HAT using an ADS4195 (signal integrity issues killed it — see [`../hardware/README.md`](../hardware/README.md)). Not reflected in this sheet at all and never a final cost, but the PCBs exist in `../hardware/oscilloscope-adc-hat/` for reference.
- **Display**: PDR lists a Waveshare 6.25" capacitive touch display, which lines up with the final report's description of "the LCD screen" — kept as-is below since nothing contradicts it, but worth a sanity-check against whatever's actually installed.

Anything not flagged above is assumed to still reflect the as-built design, but wasn't independently re-verified item-by-item against the final hardware — treat quantities in particular as a starting point to recount against actual stock/spares on hand.

## Analog Computer (modules, power distribution, housing)

| Component | Spec | Qty | Package | Manufacturer | Mfr Part # | Distributor Part # | Price/Item | Total |
|---|---|---|---|---|---|---|---|---|
| 24V PSU | 24V, 156W, 6.5A, 89% efficient, adjustable output | 2 | Chassis mount | Mean Well USA | LRS-150-24 | 1866-3321-ND | $19.99 | $39.98 |
| 12V LED | 12V, 8mm red, voltage-protected | 2 | Panel mount | FILN | N/A | FL1A-08FW-1_R_12_5 | $11.99 | $23.98 |
| Buzzer | 12V, 95dB, 20mA max | 2 | Panel mount | HiLetgo | 3-01-1588 | 3-01-1588 | $7.59 | $15.18 |
| Main power port | 125V 10A fused power socket/switch, 4.9ft cable | 2 | Chassis mount | N/A | ASDS-ZH016 | B0B4256Y2S | $15.99 | $31.98 |
| Aluminum housing | 5052 aluminum sheet, 18"x24", 1/16" | 1 | Sheet | PCB Way | — | — | $65.00 | $39.99 |
| Banana plugs | Gold-plated 3.5mm/3mm | 1 | Banana plug | LINSYRC | B09MCKKBHJ | 732688553829 | $7.99 | $7.99 |
| XT30 connector (male) | 5A/contact solid-state connector | 1 | Pin solder | Amass | XT30PW-M | XT30PW-M | $10.30 | $10.30 |
| XT30 connector (female) | 5A/contact solid-state connector | 1 | Pin solder | Amass | XT30PW-F | XT30PW-F | $10.30 | $10.30 |
| Comparator (THT) | ~36V dual comparator, 5mV input offset | 10 | Thru-hole | Texas Instruments | LM393P | 296-1398-5-ND | $0.33 | $3.31 |
| Comparator (SMT) | ~36V dual comparator, 5mV input offset | 10 | SMT | Texas Instruments | LM393DR | 296-1015-1-ND | $0.15 | $1.52 |
| Dual op-amp | 36V RRIO mux-friendly op-amp | 25 | SMT | Texas Instruments | OPA196IDR | 595-OPA196IDR | $1.01 | $25.25 |
| 3D print | UV resin printed components | 1 | N/A | — | — | — | $15.00 | $15.00 |
| Wood plank | 0.5"x5.5"x48" unfinished red oak | 1 | Box | Home Depot | BRDNAT 1-2X6X4ROAK | 333192905 | $11.71 | $11.71 |
| PCB, power rails | — | 3 | SMD/SMT | JLCPCB | — | — | $5.00 | $15.00 |
| PCB, modules | — | 12 | SMD/SMT | JLCPCB | — | — | $2.00 | $24.00 |
| PCB, motherboard | — | 3 | SMD/SMT | JLCPCB | — | — | $5.00 | $15.00 |
| Capacitor 0.1uF | MLCC | 30 | SMD/SMT | Yageo | CC1206MRY5V9BB104 | 603-CC126MRY5V9BB104 | $0.11 | $3.36 |
| Resistor 100Ω | Thick film | 200 | SMD/SMT | Panasonic | ERJ-P08J101V | 667-ERJ-P08J101V | $0.03 | $5.60 |
| Resistor 1kΩ | Thick film | 100 | SMD/SMT | TE Connectivity | CRGS1206J1K0 | 279-CRGS1206J1K0 | $0.09 | $8.80 |
| Resistor 3kΩ | Thick film | 100 | SMD/SMT | Panasonic | ERJ-T08J302V | 667-ERJ-T08J302V | $0.06 | $6.30 |
| Resistor 100kΩ | Thick film | 100 | SMD/SMT | Vishay | CRCW1206100KFKEBC | 71-CRCW1206100KFKEBC | $0.03 | $2.70 |
| Resistor 330kΩ | Thick film | 100 | SMD/SMT | Yageo | RE1206DRE07330KL | 603-RE1206DRE07330KL | $0.05 | $4.50 |
| Rocker switch | Heavy duty KCD4 | 1 | Chassis mount | N/A | B0FD8LDTS6 | B0FD8LDTS6 | $15.99 | $15.99 |
| Potentiometer | 100kΩ precision, metal shaft | 10 | Pin solder | Jebhane | RK097 | RK097 | $1.00 | $10.00 |

**Section total: $347.74**

## Mechatronic (ball-in-tube demonstrator)

| Component | Spec | Qty | Package | Manufacturer | Mfr Part # | Distributor Part # | Price/Item | Total |
|---|---|---|---|---|---|---|---|---|
| Acrylic tube | 6" x 1.5" | 1 | N/A | Mexanixxity | B0B9C6951J | B0B9C6951J | $12.59 | $12.59 |
| Sheet metal | Aluminum, 8"x12" | 1 | N/A | Lswteiz | B09YGZRKD4 | B09YGZRKD4 | $10.99 | $10.99 |
| 3D print | UV resin printed components | 1 | N/A | — | — | — | $15.00 | $15.00 |
| Banana plugs | Gold-plated 3.5mm/3mm | 1 | Banana plug | LINSYRC | B09MCKKBHJ | 732688553829 | $7.99 | $7.99 |
| Potentiometer | 100kΩ precision, metal shaft | 5 | Pin solder | Jebhane | RK097 | RK097 | $1.00 | $5.00 |
| Rocker switch | Heavy duty KCD4 | 1 | Chassis mount | N/A | B0FD8LDTS6 | B0FD8LDTS6 | $15.99 | $15.99 |
| PCB, motherboard | — | 3 | SMD/SMT | JLCPCB | — | — | $5.00 | $15.00 |
| 12V LED | 12V, 8mm red, voltage-protected | 2 | Panel mount | FILN | N/A | FL1A-08FW-1_R_12_5 | $11.99 | $23.98 |
| Buzzer | 12V, 95dB, 20mA max | 2 | Panel mount | HiLetgo | 3-01-1588 | 3-01-1588 | $7.59 | $15.18 |
| Main power port | 125V 10A fused power socket/switch, 4.9ft cable | 2 | Chassis mount | N/A | ASDS-ZH016 | B0B4256Y2S | $15.99 | $31.98 |
| Wood plank | 0.5"x5.5"x12" unfinished red oak | 1 | Box | Home Depot | BRDNAT 1-2X6X4ROAK | 333192905 | $8.99 | $8.99 |
| ~~4-channel ADC~~ | ~~12-bit SPI 100kS/s differential ADC~~ | ~~3~~ | ~~SMT~~ | ~~Microchip~~ | ~~MCP3204T-CI/SL~~ | ~~MCP3204T-CI/SLTR-ND~~ | ~~$1.72~~ | ~~$5.16~~ |
| 12V brushless motor | 6000 RPM, w/ tachometer | 1 | N/A | Robot Shop | BLDC3650-24-8000 | — | $25.00 | $25.00 |
| Screw | M3x10mm | 1 | Box | MDFLY | B00ZWASZGO | B00ZWASZGO | $2.68 | $2.68 |
| Screw terminal block | 5mm, 2-pin | 1 | SMD/SMT | SynHHergyx | B0FNQX9MMT | B0FNQX9MMT | $4.99 | $4.99 |
| Propeller | — | 1 | N/A | Wurenji | 789616070286 | 789616070286 | $8.69 | $8.69 |

The struck-through ADC line was PDR's plan and was not used in the final build (see "Known changes" above) — it's kept here crossed out rather than deleted so its cost isn't silently lost from the section total below, which still includes it as originally quoted.

**Section total: $205.77**

## Oscilloscope / Screen

| Component | Spec | Qty | Package | Manufacturer | Mfr Part # | Distributor Part # | Price/Item | Total |
|---|---|---|---|---|---|---|---|---|
| Raspberry Pi Zero 2 W | Pi Zero 2 WH | 1 | Box | Raspberry Pi | B0DKKXS4RV | B0DKKXS4RV | $27.99 | $27.99 |
| Mini HDMI to HDMI cable | HDMI 2.1 | 1 | Cable | Cable Matters | B0DP3WLGMZ | B0DP3WLGMZ | $7.99 | $7.99 |
| ~~Multiplexer~~ | ~~16-channel digital/analog mux~~ | ~~1~~ | ~~Board~~ | ~~HiLetgo~~ | ~~CD74HC4067~~ | ~~CD74HC4067~~ | ~~$5.69~~ | ~~$5.69~~ |
| Display | 6.25" capacitive touch | 1 | Thru-hole | Waveshare | B0CW35VK1B | B0CW35VK1B | $79.99 | $79.99 |
| **Waveshare ADS1263 ADC HAT** | 10-channel, 32kSPS ADC — replaces the multiplexer above | — | — | Waveshare | — | — | — | **TBD** |

Same deal on the struck-through multiplexer line — not used in the final build, kept for the record. The ADS1263 HAT that replaced it is the one missing price/part number in this whole document; whoever picks this up should add it once they've got the actual purchase info.

**Section total (excluding the still-TBD ADS1263 HAT): $121.66**

## Grand total (as quoted at PDR, both superseded lines included, ADS1263 HAT excluded)

**$675.17**

This number is not the real final cost of the project — it predates the ADC redesign, the abandoned custom ADC HAT attempt, and whatever the finance manager's actual final purchasing looked like. It's a starting point, not a final figure.

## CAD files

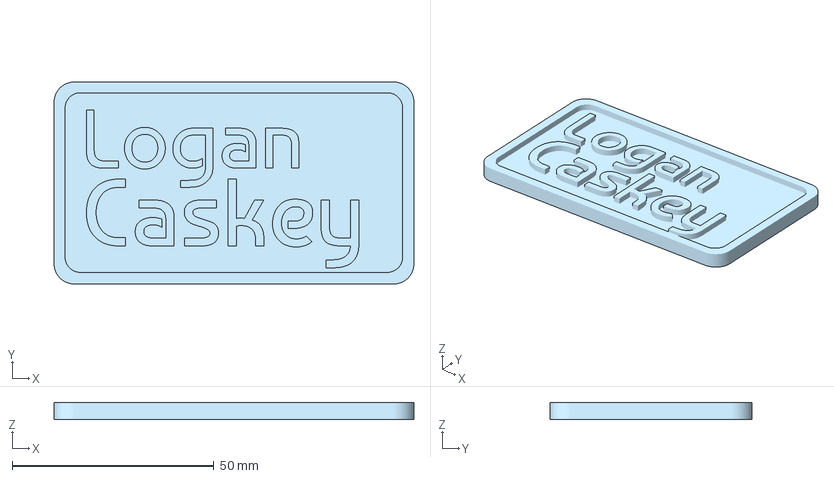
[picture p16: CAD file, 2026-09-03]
mechanical/Module_Blank.3mf
89.3 x 50.1 x 4.32 mm

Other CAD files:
mechanical/Adder_Face.x_t
mechanical/Banana_Plug_Adapter.x_t
mechanical/Cable_Holder.x_t
mechanical/Gain_Face.x_t
mechanical/Integrator_Face.x_t
mechanical/Main_Body_Assembly.x_t
mechanical/Module_Assembly.x_t
mechanical/Module_Blank.x_t
mechanical/Oscilloscope_Assembly.x_t
mechanical/Switch_Face.x_t

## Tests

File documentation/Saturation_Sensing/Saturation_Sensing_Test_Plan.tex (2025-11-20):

\documentclass[12pt]{article}

%-----------------------------
% Packages
%-----------------------------
\usepackage{geometry}
\geometry{margin=1in}
\usepackage{titlesec}
\usepackage{hyperref}
\usepackage{enumitem}
\usepackage{longtable}
\usepackage{graphicx}
\usepackage{float}

\title{Saturation Sensing Test Plan}
\author{Jurrasic Spark Senior Design Team}

%-----------------------------
% Document
%-----------------------------
\begin{document}
\maketitle
\tableofcontents
\newpage

%-----------------------------
\section{Introduction}

This document aims to outline a testing protocol for rapid reproduction and verification of the portion of the modules within our analog computer that detect when an op-amp is being driven to saturation. We will first discuss the circuit design and ideal operations, then follow it up with the actual circuit, discussing acceptable margins for the ciruit, and realistic operating conditions.

%-----------------------------
\newpage
\section{Circuit Design}

This circuit at it's core is a simple window comparator circuit, with a few caveats. If you were to look up a window comparator circuit online, they are typically shown to be made with op-amps, and have active-high logic. In our design, we use LM393 comparators, which are active low devices and provide a sink for current when the device is active. Below is the circuit design. 

\begin{figure}[h]
	\centering
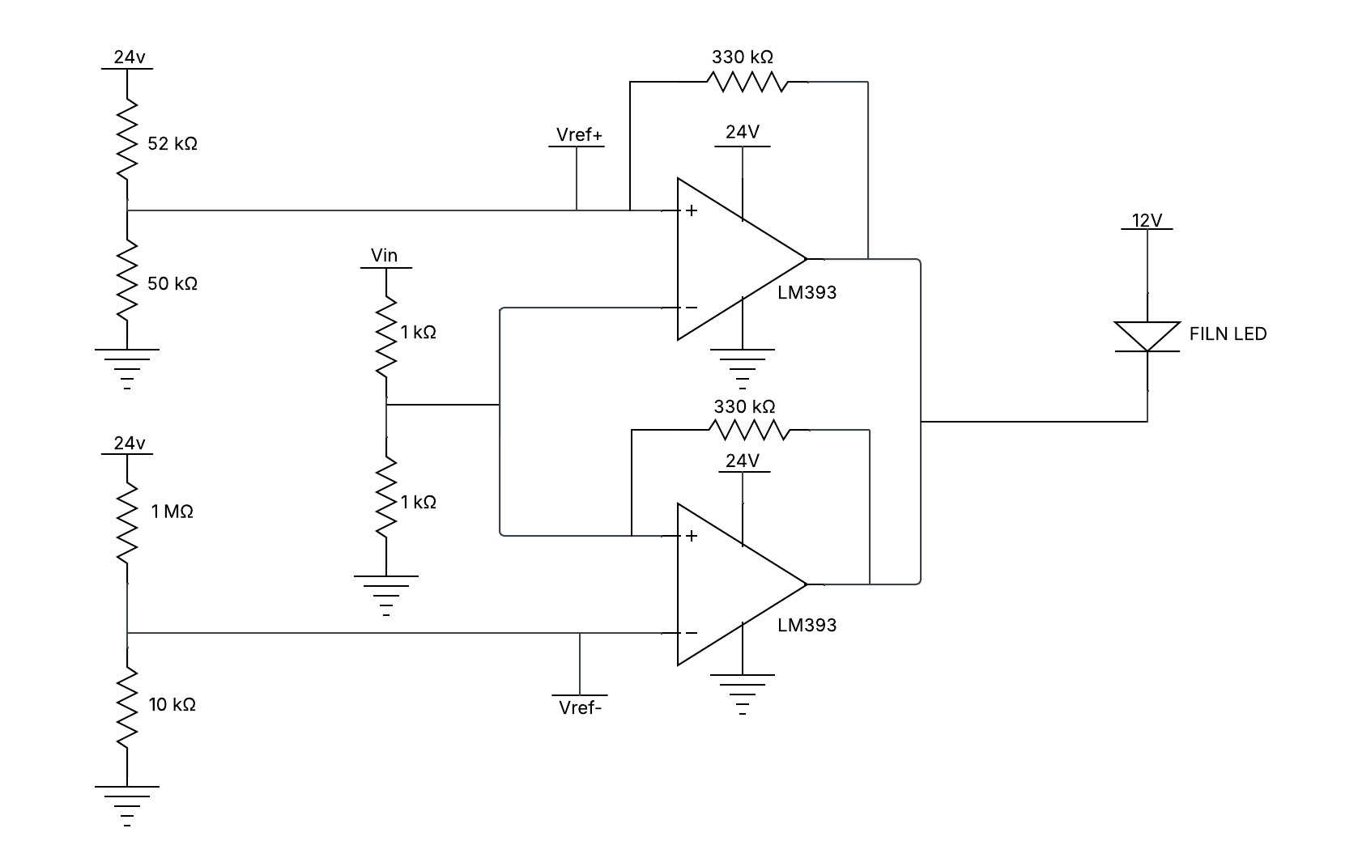
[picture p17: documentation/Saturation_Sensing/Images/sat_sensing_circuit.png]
	
	\caption{Saturation Sensing Circuit}
\end{figure}

As you can see, there are a good amount of voltage dividers included in this circuit. This is due to the fact that the LM393 comparators can only accept input voltages up to $VCC-1.5V$, meaning that since they are powered by our system voltage of $24V$, the maximum voltage that is allowable on inputs is $22.5$ volts. To counteract this, we divide our input voltage by 2, meaning our input voltages range from $0-12V$. We also account for this in generating our reference voltages. The saturation sensing triggers when outputs are within $0.5V$ of it's maximum or minimum, i.e. it will trigger when voltages are either at $0.5V$, or $23.5V$. Thus, we calculate our resistance values for generating the reference voltages to be such that $V_{ref}^+ = 11.75V$ and $V_{ref}^- = .25V$. Note that the resistances for generating the $11.75V$ reference voltage are not typical resistor values, and require the use of trimming potentiometers to get accurate resistances.

The FILN LED acts as a pull up resistor in this situation, and there is no series current-limiting resistance with this LED as the LED we chose is a self-contained unit, i.e. they already include a current limiting resistor in the package itself. The $330k\Omega$ resistors are to provide slight hysteresis to the circuit, minimizing comparator chatter and thus helping the LED's to not flicker. 

The comparators work by comparing the voltages seen at the non-inverting ($V+$) and inverting ($V-$) nodes, and if $V+ > V-$, the LM393 is "off" and effectively acts like an open circuit. If $V- > V+$, the LM393 "turns on", and effectively acts like a short circuit to ground, i.e. it sinks current. This allows current to flow through the LED and gets dumped through the LM393 to ground, completing the circuit and turning the LED on. The LED itself when connected directly to 12 volts pulls $3.4 mA$ of current, which is well within acceptable ranges for the LM393 to sink, and in actuality due to the offset output voltage when the LM393 is "on", the LED will actually consume slightly less current, and is not a point of consideration for this testing plan. 

%----------------------------
\newpage
\section{Testing Protocol}

This testing protocol assumes that the circuit has already been built, and omits the steps required to build the circuit itself. We also will omit the steps for building a circuit to generate a 12 volt line for the pullup voltage, however it is required to have this 12 volt line for testing. We recommend building a simple voltage divider circuit and buffering the output with a voltage follower circuit for a nice, steady 12 volts that's somewhat resistent to any transients experienced in the supply line (which is extremely unlikely) given this setup). We also recommend using a potentiometer connected to the 24 volt line to easily and quickly test on our entire 0-24 volt range. Given these prerequisites, the steps to the test plan are as follows: 

\begin{enumerate} 
	\item Power on your 24 volt supply.
	\item Verify that the voltage divider circuit for generating $12V$ is working correctly, and you have an even $12 \pm .05 mV$ line. 
	\item Verify that your reference voltages are within $\pm 25 mV$ of the ideal value (note that this is the biggest inconsistency that will be seen, as resistors will have innate innacuracy/tolerances that cause the voltage division to be slightly less accurate, however this is more than ok for this application). 
	\item With reference voltages and 12 volt line verified, use a potentiometer hooked up to the 24 volt power, with its middle (output) pin connected to the input of the saturation sensing circuit.
	\item First we will test the middle range of voltages (i.e. $0.5V < V_{in} < 23.5V$). With $V_{in}$ in this range, verify that the output of the LM393 comparators doesn't ever get less than $~10V$. As $V_{in}$ approaches $11.5V$, the output voltage is higher than as $V_{in}$ approaches $0V$, therefore the "low-side" detection is much more important to verify that this holds. The LED will turn on with output voltages as high as $~7.8V$, therefore the absolute minimum accepted output voltage for this needs to exceed this with headroom, thus $~10V$ is ideal. 
	\item We now will verify the outer ranges for input voltages, i.e. $V_{in} < .5V$ and $V_{in} > 11.5V$. Probing the same output of the comparators, turn the potentiometer all the way such that $V_{in} = 24V$. Verify that the output voltage doesn't exceed $150 mV$. The same should hold for the low side ($V_{in} < 0.5V$).
	\item With these values verified, the circuit should be operating within acceptable ranges, and correct relationship between input voltage and the LED being turned on can now be observed.
\end{enumerate}

%-----------------------------
\newpage 
\section{Example Test Procedure/Values}

In this section, we will demonstrate an example of this circuit built out on a breadboard, with each value tested to show a sort of "real life" example for this circuit. Below is an image showing the circuit built out on the breadboard: 

\begin{figure}[H]
	\centering
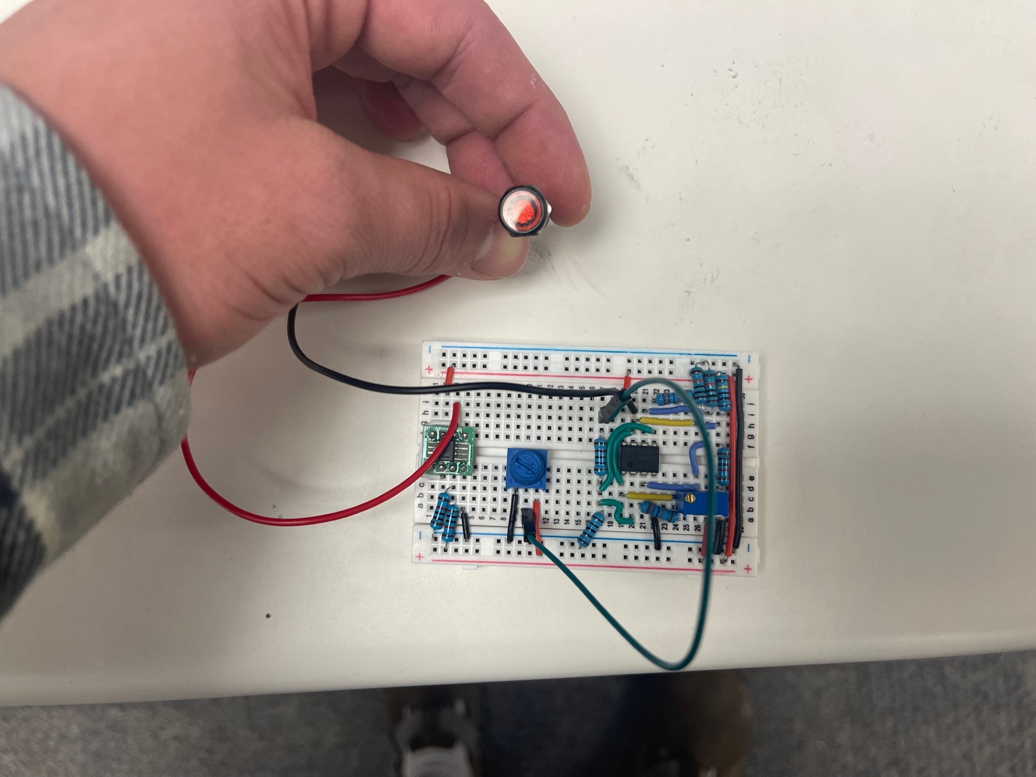
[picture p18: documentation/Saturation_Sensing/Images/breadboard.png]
	
	\caption{Saturation Sensing Circuit Built on a Breadboard}
\end{figure}

This is just to show the circuit built out, and isn't necessarily intended to be used for reference. Following the above testing procedure, we will begin by testing the $12V$ line and verifying that it is within acceptable boundaries: 

\begin{figure}[H]
	\centering
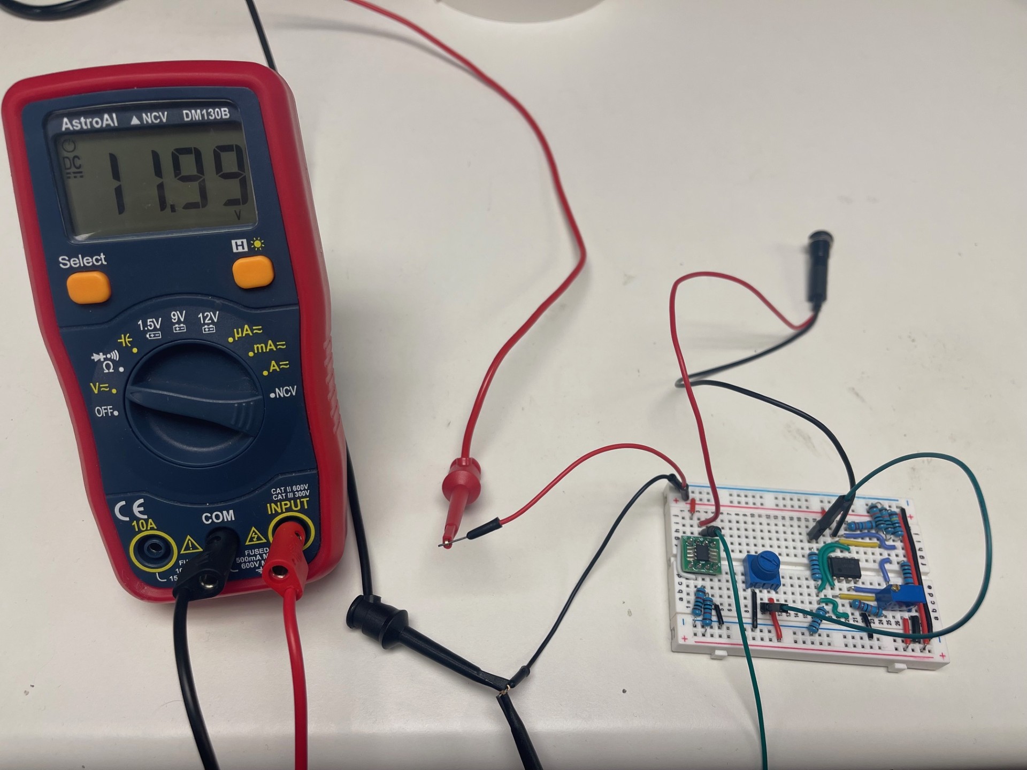
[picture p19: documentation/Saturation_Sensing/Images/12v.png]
	
	\caption{12V Line Measurement}
\end{figure}

Now, we will verify that our reference voltages are within an acceptable range. Below is the measurement for the $250mV$ reference voltage: 

\begin{figure}[H]
	\centering
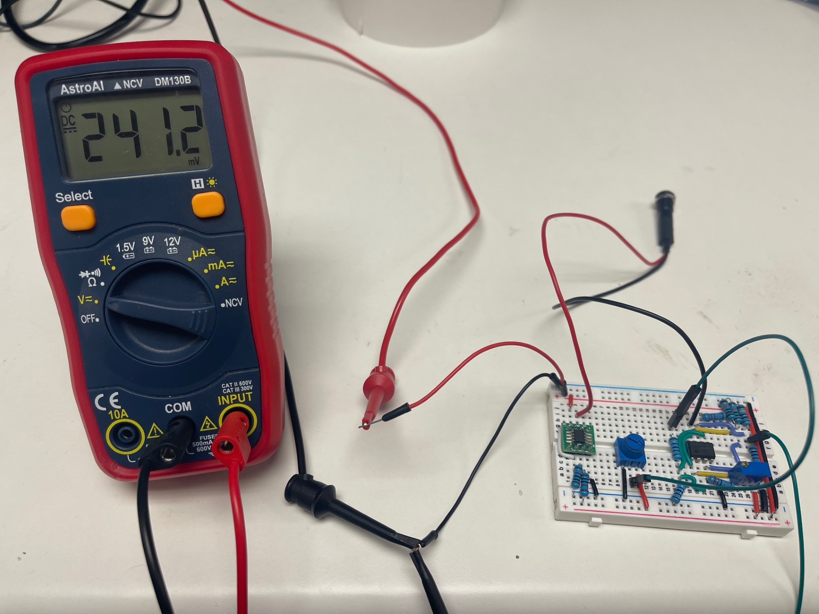
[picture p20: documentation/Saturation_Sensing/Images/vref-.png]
	
	\caption{Low-side Reference Measurement}
\end{figure}

Doing the same for the $11.75V$ reference: 

\begin{figure}[H]
	\centering
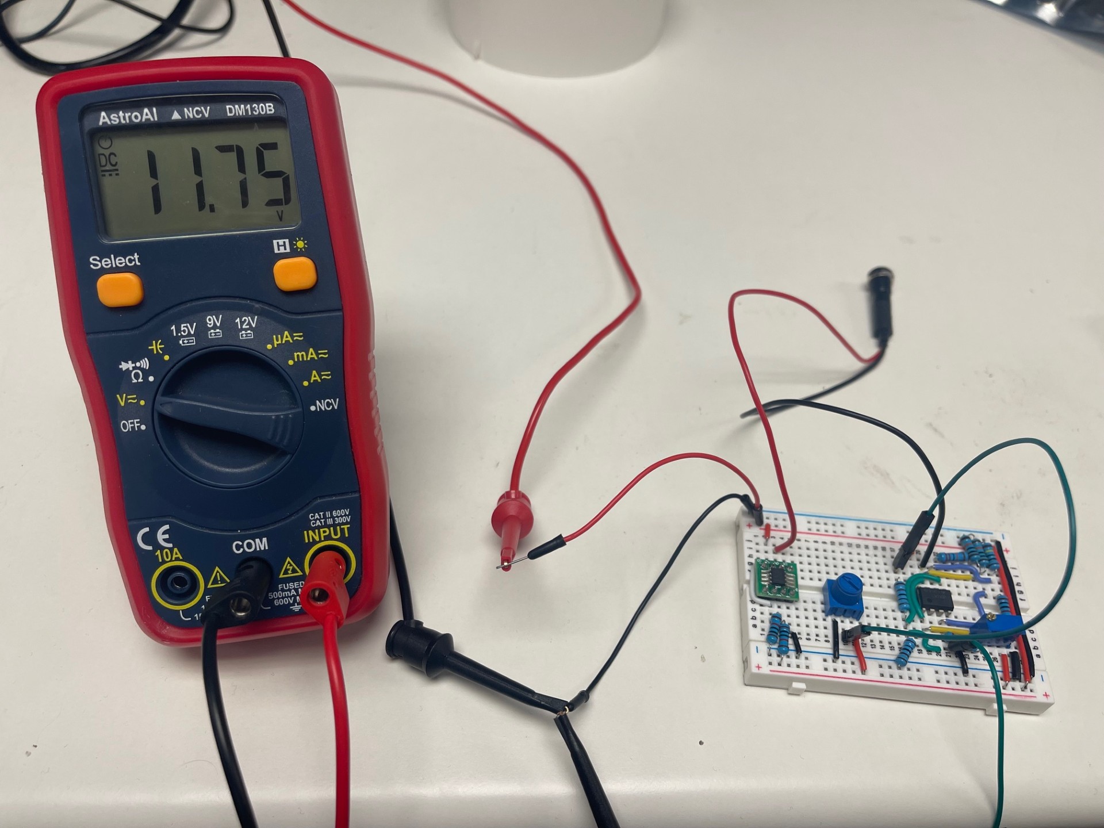
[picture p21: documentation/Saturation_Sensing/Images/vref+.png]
	
	\caption{High-side Reference Measurement}
\end{figure}

Now, with a potentiometer hooked up as the input voltage, we will measure the output of the comparators near the upper end and lower end to verify that the output never gets below $~10V$: 

\begin{figure}[H]
	\centering
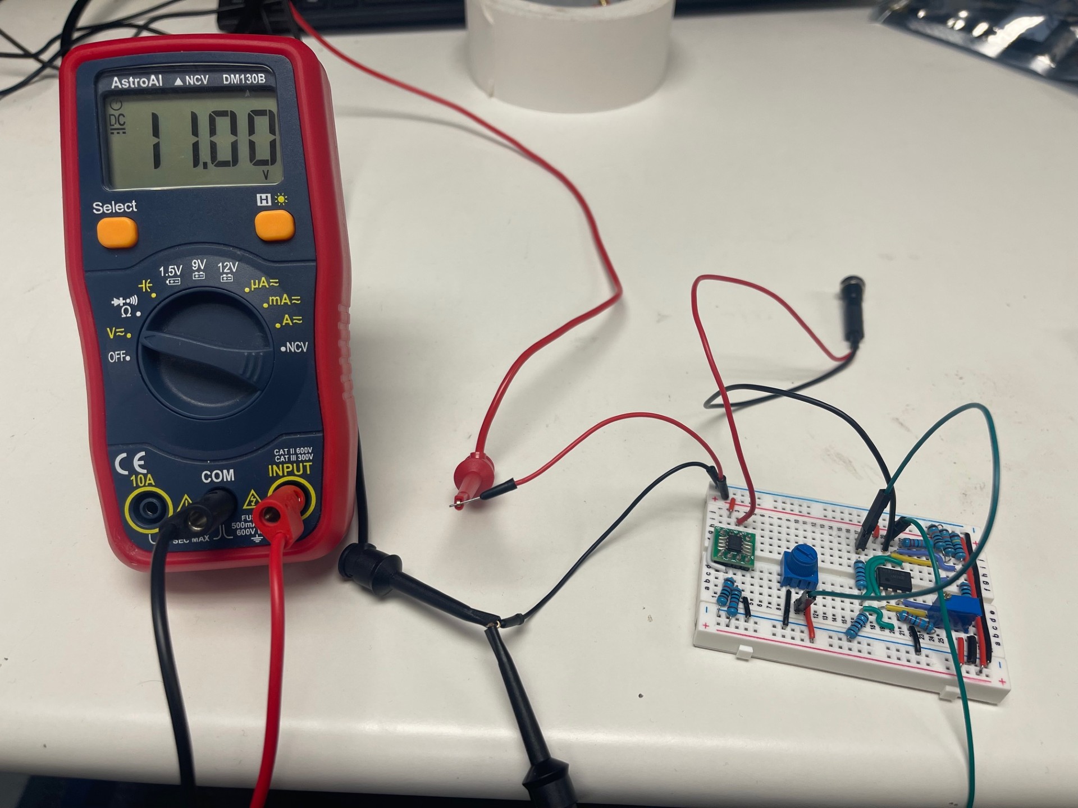
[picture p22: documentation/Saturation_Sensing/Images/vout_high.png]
	
	\caption{Comparator output when $V_{in}$ Approaches $23.5V$}
\end{figure}

Doing the same for low-side: 

\begin{figure}[H]
	\centering
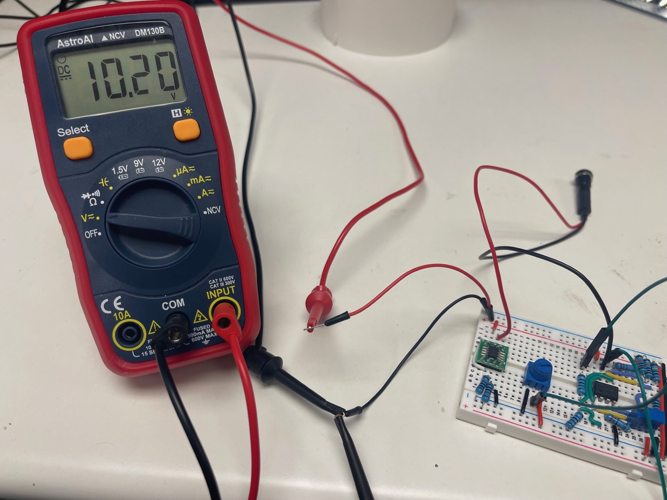
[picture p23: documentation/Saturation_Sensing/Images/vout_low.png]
	
	\caption{Comparator output when $V_{in}$ approaches $0.5V$}
\end{figure}

Now, we will verify that the output doesn't exceed $150mV$ at both low and high-side detection (i.e. when the LM393 turns "on"):

\begin{figure}[H]
	\centering
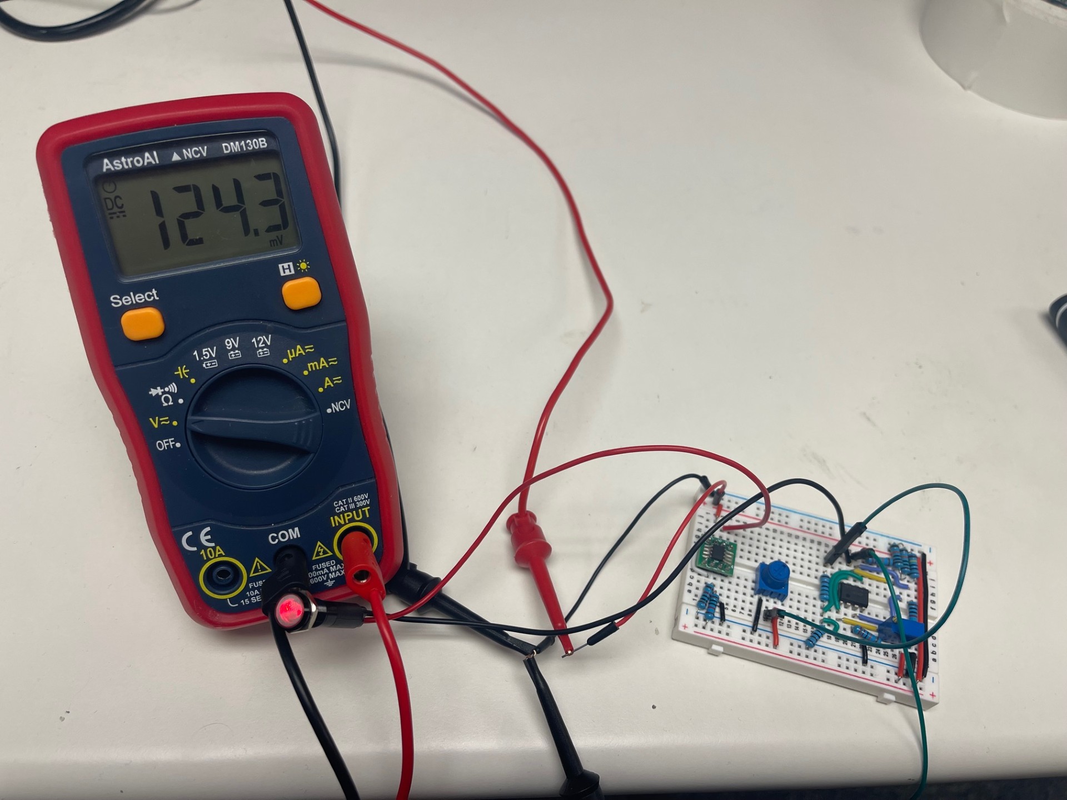
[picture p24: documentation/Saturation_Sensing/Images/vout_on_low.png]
	
	\caption{Output when $V_{in} < 0.5V$}
\end{figure}

\begin{figure}[H]
	\centering
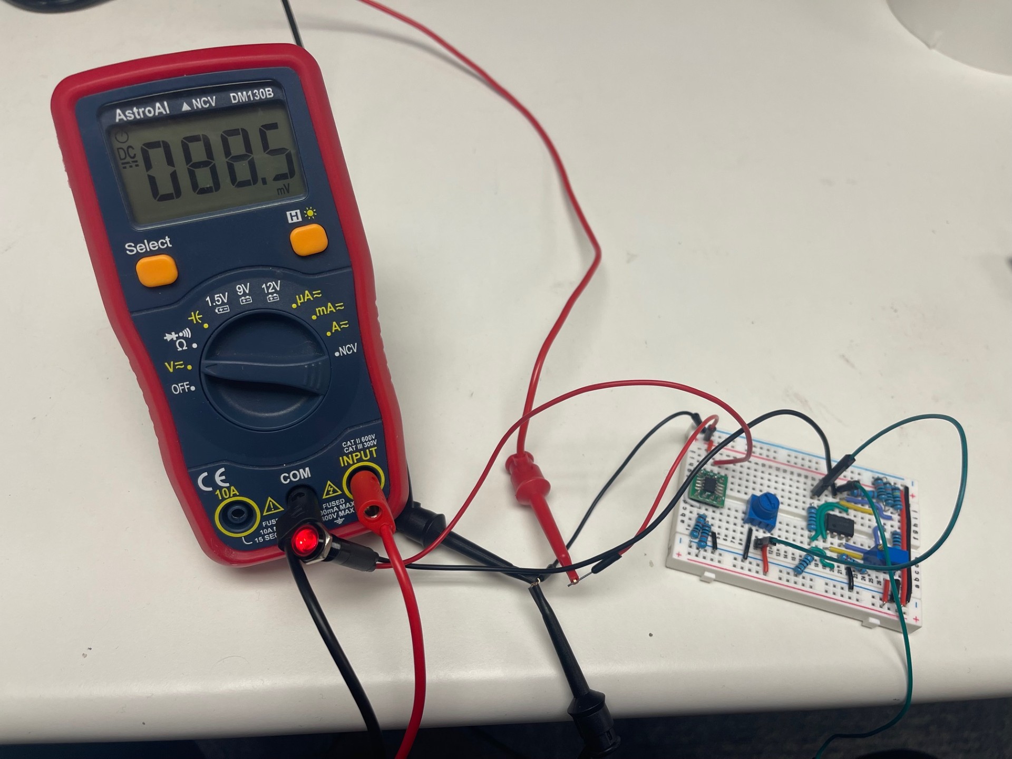
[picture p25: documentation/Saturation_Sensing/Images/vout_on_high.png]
	
	\caption{Output when $V_{in} > 11.5V$} 
\end{figure} 

\end{document}

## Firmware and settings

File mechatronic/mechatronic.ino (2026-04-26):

#include <Wire.h>
#include <VL53L1X.h>

#define FAN_PWM 9
#define TOF_PWM 5

// ROI size (SPADs): 4 is the minimum, 16 is full FOV.
// Smaller = narrower field of view = less acrylic tube wall in the measurement.
// Start at 4 and increase if you get frequent signal-fail readings.
#define ROI_SIZE 4

VL53L1X sensor;

const int ctrlSigPin = A0;

const uint8_t PWM_AT_TOP    = 255;
const uint8_t PWM_AT_BOTTOM = 127;
const float   MAX_RANGE_MM  = 889.0;  // 35 in -- physical tube height

int16_t distance_mm = 0;

void busRecover() {
  pinMode(SCL, OUTPUT);
  pinMode(SDA, OUTPUT);
  digitalWrite(SDA, HIGH);
  for (int i = 0; i < 9; i++) {
    digitalWrite(SCL, HIGH); delayMicroseconds(5);
    digitalWrite(SCL, LOW);  delayMicroseconds(5);
  }
  digitalWrite(SDA, LOW);  delayMicroseconds(5);
  digitalWrite(SCL, HIGH); delayMicroseconds(5);
  digitalWrite(SDA, HIGH); delayMicroseconds(5);
  TWCR = 0;
  pinMode(SCL, INPUT);
  pinMode(SDA, INPUT);
}

void setup() {
  Serial.begin(115200);
  Serial.println("Serial OK");

  pinMode(FAN_PWM, OUTPUT);
  pinMode(TOF_PWM, OUTPUT);

  // Timer1: 25 kHz PWM on D9 (OC1A)
  TCCR1A = 0; TCCR1B = 0; TCNT1 = 0;
  ICR1   = 639;
  OCR1A  = 0;
  TCCR1A = (1 << COM1A1) | (1 << WGM11);
  TCCR1B = (1 << WGM13)  | (1 << WGM12) | (1 << CS10);

  busRecover();
  Wire.begin();
  Wire.setClock(400000);
  delay(100);

  sensor.setTimeout(500);
  if (!sensor.init()) {
    Serial.println("Failed to init VL53L1X");
    while (1) delay(10);
  }
  Serial.println("VL53L1X ready");

  sensor.setDistanceMode(VL53L1X::Long);
  sensor.setMeasurementTimingBudget(50000);
  // Narrow the ROI to reduce tube-wall reflections.
  sensor.setROISize(ROI_SIZE, ROI_SIZE);
  sensor.startContinuous(50);

  delay(100);
}

void loop() {
  // Fan control -- direct map: 0V -> off, 5V -> full speed
  int adc = analogRead(ctrlSigPin);
  uint16_t ocr = (uint32_t)adc * ICR1 / 1023;
  OCR1A = ocr;

  // Distance
  uint16_t reading = sensor.read(false);

  if (sensor.timeoutOccurred()) {
    Serial.println("TIMEOUT");
  } else if (sensor.ranging_data.range_status == VL53L1X::RangeValid) {
    distance_mm = (int16_t)reading;
  }

  // Map raw distance directly to PWM -- no remapping needed
  // 0 mm (top)       -> PWM 255
  // 889 mm (bottom)  -> PWM 127
  float frac = (float)distance_mm / MAX_RANGE_MM;
  if (frac < 0.0) frac = 0.0;
  if (frac > 1.0) frac = 1.0;
  uint8_t pwmValue = (uint8_t)(PWM_AT_TOP - frac * (PWM_AT_TOP - PWM_AT_BOTTOM));
  analogWrite(TOF_PWM, pwmValue);

  Serial.print("adc=");      Serial.print(adc);
  Serial.print("  OCR1A=");  Serial.print(OCR1A);
  Serial.print("  status="); Serial.print((int)sensor.ranging_data.range_status);
  Serial.print("  mm=");     Serial.print(distance_mm);
  Serial.print("  in=");     Serial.print((float)distance_mm / 25.4, 1);
  Serial.print("  PWM5=");   Serial.println(pwmValue);
}

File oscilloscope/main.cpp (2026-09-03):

// Copyright (C) 2023 The Qt Company Ltd.
// SPDX-License-Identifier: LicenseRef-Qt-Commercial OR BSD-3-Clause

/*!
 * \file main.cpp
 * \brief App entry point: wires DataSource and BluetoothExporter into the
 * QML context and loads main.qml.
 */

#include "bluetoothexporter.h"
#include "datasource.h"

#include <QApplication>
#include <QDir>
#include <QQmlContext>
#include <QQmlEngine>
#include <QQuickView>

int main(int argc, char *argv[])
{
    // Qt Charts uses Qt Graphics View Framework for drawing, therefore QApplication must be used.
    QApplication app(argc, argv);

    // OpenGL backend is required to make AbstractSeries.useOpenGL work.
    // We don't force it programmatically, as OpenGL is not guaranteed to be available everywhere.
    bool openGLSupported = QQuickWindow::graphicsApi() == QSGRendererInterface::OpenGLRhi;
    if (!openGLSupported) {
        qWarning() << "OpenGL is not set as the graphics backend, so AbstractSeries.useOpenGL will not work.";
        qWarning() << "Set QSG_RHI_BACKEND=opengl environment variable to force the OpenGL backend to be used.";
    }

    QQuickView viewer;

    // The following are needed to make examples run without having to install the module
    // in desktop environments.
#ifdef Q_OS_WIN
    QString extraImportPath(QStringLiteral("%1/../../../../%2"));
#else
    QString extraImportPath(QStringLiteral("%1/../../../%2"));
#endif
    viewer.engine()->addImportPath(extraImportPath.arg(QGuiApplication::applicationDirPath(),
                                      QString::fromLatin1("qml")));
    QObject::connect(viewer.engine(), &QQmlEngine::quit, &viewer, &QWindow::close);

    viewer.setTitle(QStringLiteral("QML Oscilloscope"));

    DataSource dataSource(&viewer);
    viewer.rootContext()->setContextProperty("dataSource", &dataSource);
    viewer.rootContext()->setContextProperty("openGLSupported", openGLSupported);

    BluetoothExporter btExporter;
    viewer.rootContext()->setContextProperty("btExporter", &btExporter);

    viewer.setSource(QUrl("qrc:/qml/qmloscilloscope/main.qml"));
    viewer.setResizeMode(QQuickView::SizeRootObjectToView);
    viewer.setColor(QColor(0x404040));
    viewer.showFullScreen();

    const int result = app.exec();

    // Clear these before dataSource/btExporter are destroyed below.
    // Otherwise, QML's teardown could touch freed object through active binding. 
    viewer.rootContext()->setContextProperty("dataSource", nullptr);
    viewer.rootContext()->setContextProperty("btExporter", nullptr);

    return result; 
}

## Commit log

2025-10-16 Updated schematics for modules
2026-01-09 circuit schematics added
2026-02-10 settings drawer, toggle buttons
2026-02-17 bug fix, circular buffer
    [datasource.cpp, datasource.h]
2026-02-24 refactor datasource, trigger on channel, 4 channel. TODO: ui improvements (button coloring), extend trigger functionality
2026-03-30 Add PiZero ADC PCB Layout
    [PiZero2W.PrjPcb]
2026-03-30 Add Integrator Layout
    [Integrator.PrjPcb]
2026-03-30 Remove Integrator
    [Integrator.PrjPcb]
2026-03-30 remove PiZero layout
    [PiZero2W.PrjPcb]
2026-03-30 Add ADC Pi Hat PCB Layout
    [PiZero2W_Hat.PcbDoc]
2026-03-30 Add Integrator Module Layout
    [Integrator.PcbDoc]
2026-03-30 Add Adder Module Layout
    [Adder.PcbDoc]
2026-03-30 Add Gain Module Layout
    [Gain.PcbDoc]
2026-03-30 Add Left Power Module Layout
    [Power_Left.PcbDoc]
2026-03-30 Add Middle Power Module Layout
    [Power_Middle.PcbDoc]
2026-03-30 Add Right Power Module Layout
    [Power_Right.PcbDoc]
2026-03-30 add left power module schematic
    [Power_Left.SchDoc]
2026-03-30 add middle power module schematic
    [Power_Middle.SchDoc]
2026-03-30 add right power module schematic
    [Power_Right.SchDoc]
2026-03-30 add gain module schematic
    [Gain.SchDoc]
2026-03-30 add integrator module schematic
    [Integrator.SchDoc]
2026-03-30 add adder module schematic
    [Adder.SchDoc]
2026-03-30 add adc hat schematic
    [PiZero2W_Hat.SchDoc]
2026-04-13 current mechatronic (VL53L0x)
2026-04-28 mechatronic and sub
    [ECEN4620_JurassicSpark_SubModule.PcbDoc, Mechatronic.PcbDoc, Mechatronic.SchDoc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]
2026-09-03 oscilloscope: merge fixed sources from code audit
    Correctness/perf fixes to ADC startup and thread-safety, CSV export
    locking and stale-data guards, Bluetooth OBEX transfer completion race,
    GPIO error handling and chip selection, ADS1263 filter/data-rate config,
    QML modal drawer input blocking, ToggleButton enabled-shadowing, and
    destruction order in main.cpp. Also removes dead signal wiring
    (setSignalType, frameReady) and the stale qmloscilloscope.pro
    (superseded by CMakeLists.txt).
    [datasource.cpp, datasource.h, main.cpp]
2026-09-03 hardware: reorganize PCB files into per-board folders
    Replaces the parallel pcb_layout/ + pcb_schematic/ trees with hardware/,
    grouping each board's .SchDoc and .PcbDoc together: modules/{Adder,Gain,
    Integrator,Subtractor}, power/, oscilloscope-adc-hat/, mechatronic/.
    Matches the folder structure already used in the team's own final
    submission package (Design Files/PCB Files/*).
    Also fixes a naming leftover: pcb_layout/ECEN4620_JurassicSpark_SubModule.PcbDoc
    is the Subtractor module's layout (confirmed by matching content against
    the final submission's Subtractor/Subtractor.PcbDoc) — renamed accordingly.
    [Adder.PcbDoc, Adder.SchDoc, Gain.PcbDoc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]
2026-09-03 mechanical: add enclosure/housing CAD from final submission package
    Parasolid (.x_t) exports covering the module housing (blank shell, per-
    module front faces for Adder/Gain/Integrator/Switch), the banana-plug
    adapter, cable holder, and full assemblies (Module, Oscilloscope, Main
    Body). Plus a .3mf of the blank module housing, ready to slice/print.
    These previously existed only in the final submission zip on a laptop
    (Design Files/CAD/), not in this repo. Editable source likely still
    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
    [Adder_Face.x_t, Banana_Plug_Adapter.x_t, Cable_Holder.x_t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]
2026-09-03 oscilloscope: add subsystem README and Doxygen setup
    README covers the acquisition pipeline (ADS1263 wiring, ring buffer,
    trigger, EMA filter, auto-calibrated view window), export paths (CSV,
    Bluetooth OBEX), build instructions, and the known noise-floor issue
    (root cause + what a future PCB rev should fix). Points at
    hardware/oscilloscope-adc-hat/ for the ADC HAT design files.
    Doxyfile scopes doc generation to the C++ backend (datasource/
    bluetoothexporter/main), using README.md as the generated mainpage.
    Headers already carry Doxygen-formatted comments; added matching \file
    briefs to the .cpp files. QML is intentionally left out of the Doxygen
    scope and documented in prose in the README i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
    [datasource.cpp, main.cpp]
2026-09-03 oscilloscope: document the cross-compile/deploy workflow in full
    Corrects an earlier wrong claim (armv6/armv7) -- target is actually Pi
    OS Bookworm 64-bit (aarch64). Documents the two one-time setup pieces
    deploy.fish/toolchain.cmake depend on, reconstructed from what's
    actually installed on the dev machine (the qt-cross-bookworm:dev image
    had no recorded Dockerfile -- built by hand via apt-get + docker commit
    -- so this Dockerfile is written from its real dpkg -l output, not
    guessed):
    - A sysroot rsync'd directly off a real Pi (not apt multiarch), so
    target Qt6 libs/headers exactly match what's on-device.
    - A Docker image with the aarch64 cross-compiler + a HOST-native Qt6
    install (moc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
2026-09-07 docs: root README polish, hardware README, oscilloscope README reflow
    - fix branch-name typo (windows-bluetooth-paring-proposal -> pairing) in
    root README's Recommended Next Steps
    - add hardware/README.md noting the abandoned ADS4195 custom ADC HAT attempt
    - rename Saturation_Sensing test plan to its current name
    - reflow oscilloscope/README.md to one-line-per-paragraph, fixing corruption
    left over from an nvim buffer-desync (truncated sentence, spliced fragment,
    mangled QtCreator link) and adding the SSH-over-school-wifi network note
    - add jurassic_spark.jpg (untracked, not yet referenced anywhere)
2026-09-07 docs: add master BOM from the PDR costing tab
    Finance manager never delivered a final BOM, so this is built from the
    PDR-stage parts-costing tab (the "PDR" tab of the seed-funding sheet, not
    the stale Phase 1 tab previously linked). Organized into Analog Computer,
    Mechatronic, and Oscilloscope/Screen sections matching the source sheet.
    Flags known superseded items rather than silently dropping them:
    - oscilloscope multiplexer + per-channel ADC plan, replaced by the single
    Waveshare ADS1263 ADC HAT actually used (price/part# still TBD)
    - mechatronic MCP3204 ADCs, replaced by a VL53L0x distance sensor per the
    final Arduino firmware
    Root README's Repository Structure bullet now points at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
2026-09-07 docs: point Repository Structure at the final report PDF
    Logan decided to keep the final report in documentation/ after all (useful
    background, unlike the other class deliverables which are staying out
    since they're stale/inaccurate) — link it from the same bullet as the BOM.
